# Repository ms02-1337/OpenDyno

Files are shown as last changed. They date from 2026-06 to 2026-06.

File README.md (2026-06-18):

# OpenDyno - Open Dynamometer System

> Professional open-source motor dynamometer testing platform.







📖 **Read the full development story:** [Building a Dynamometer From Scratch](https://blog.ms02.es/posts/building-a-dynamometer-from-scratch/)

---

## Overview

**OpenDyno** is a complete open-source dynamometer software and hardware system designed for precise motor/engine performance testing. It is built primarily to control eddy current brakes (it should also support inertia brakes, though this is currently untested).

---

## Architecture

The project is divided into three core parts:

| Component | Description |
|---|---|
| **DynoPower** | A power stage PCB designed to control the energy delivered to the eddy current brake. |
| **DynoLogic** | A control PCB running custom firmware. It is responsible for controlling the entire system, executing the logic software, running the PID loops, and managing all safety controls. |
| **DynoServer**| A Flask-based server that can run on a Raspberry Pi or any standard computer. It connects to DynoLogic via CAN bus and acts as the system's user interface. Using WebSockets, it serves a webpage to the browser, allowing the user to configure settings, start/stop tests, store and analyze data, and monitor the brake in real time. |

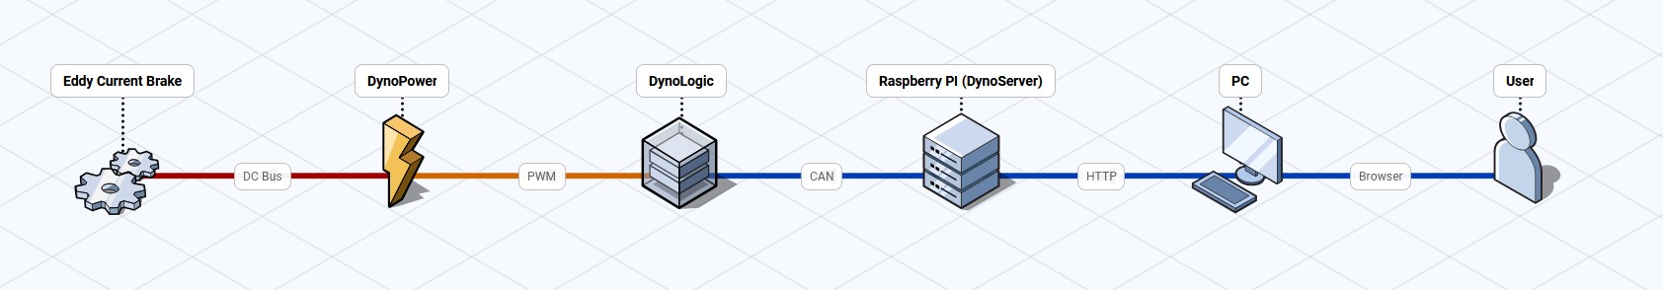
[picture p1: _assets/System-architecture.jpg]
System Architecture


### Auxiliary Hardware
- **IGBT Power**: An auxiliary power supply board that converts AC mains to 15V to power the IGBT gate driver on the DynoPower board.
  - *Note*: This board is designed to output both +15V and -5V, but **only the positive (+15V) components need to be populated** for the OpenDyno system.

## System

### DynoLogic
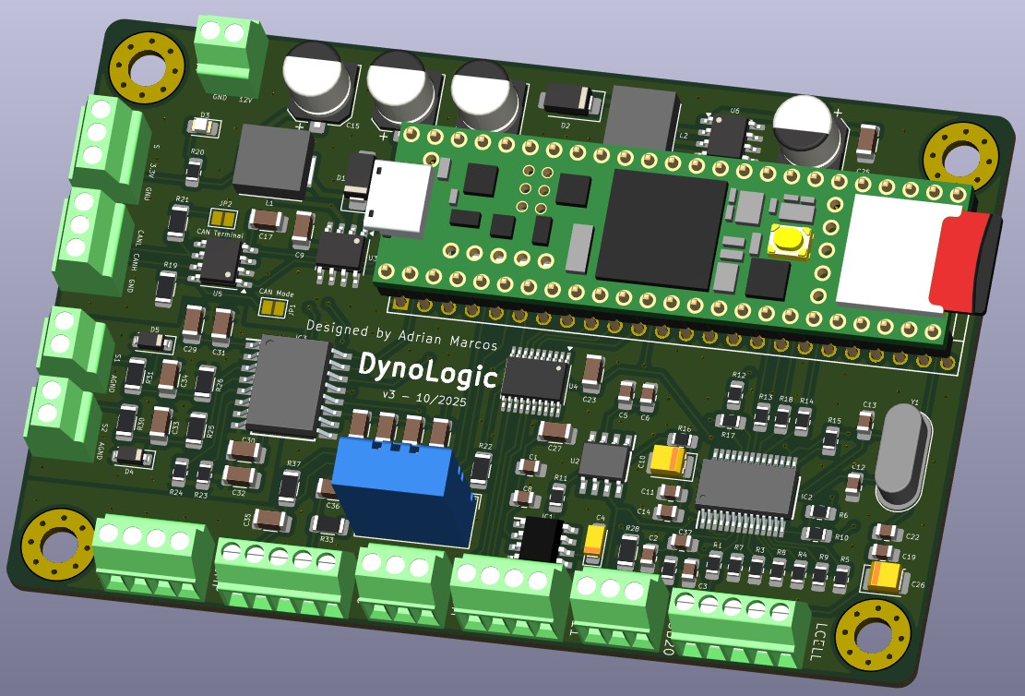
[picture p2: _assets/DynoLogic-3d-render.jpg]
DynoLogic 3D Render


### DynoPower
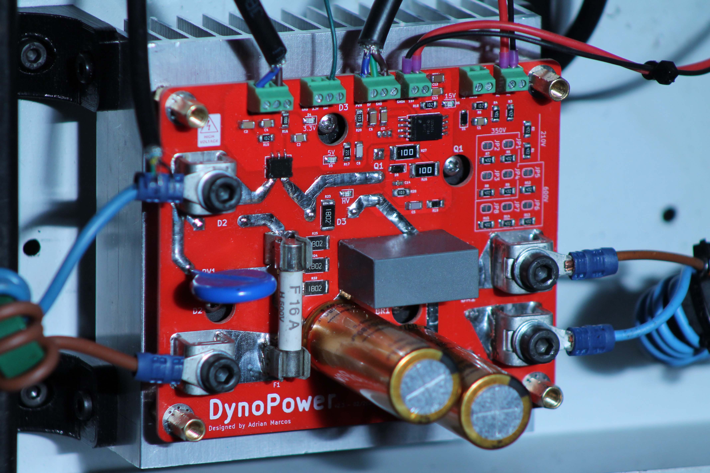
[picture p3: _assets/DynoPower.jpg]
DynoPower PCB


### DynoServer
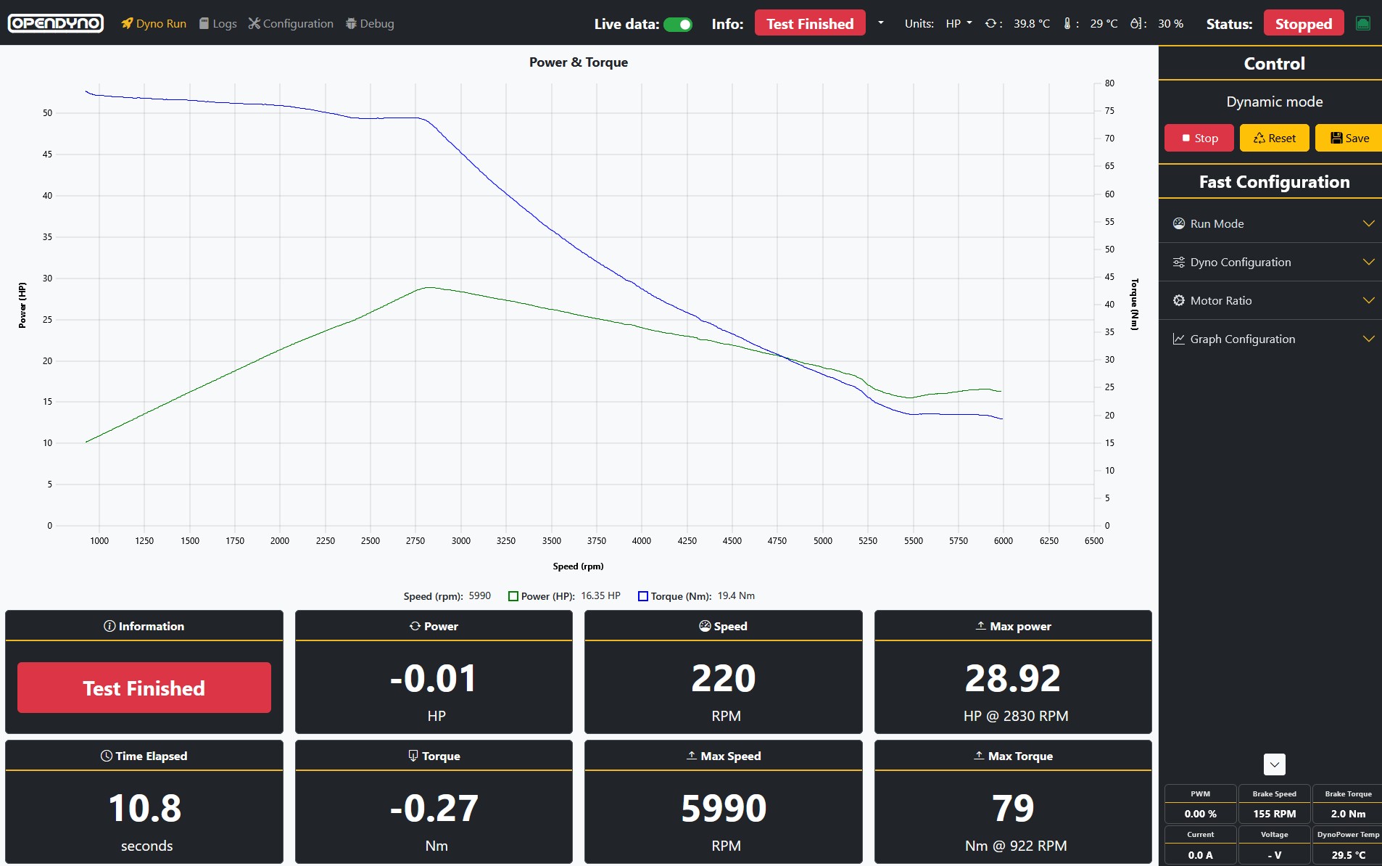
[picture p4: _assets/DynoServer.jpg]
DynoServer


---

## Key Features

- **Four Control Modes**: Constant Torque, Constant Speed, Dynamic Testing (automated state machine), and Acceleration Rate Control.
- **Real-Time Telemetry**: 100 Hz live data streaming (speed, torque, power, acceleration) via WebSocket.
- **PID Control**: High-frequency closed-loop PID control running at 1 kHz for maximum responsiveness.
- **Data Filtering**: Built-in signal processing including filters to ensure smooth and accurate sensor readings (e.g., from the load cell).
- **Thermal Monitoring**: Support for multiple temperature sensors to monitor brake and ambient temperatures.
- **Safety Limits**: User-configurable maximum speed and maximum PWM limits to protect the eddy current brake from thermal runaway, alongside minimum speed protection, a heartbeat watchdog, and emergency stop.
- **Web Interface**: Responsive UI with live charts.
- **Test Comparison**: Built-in capability to overlay and compare two different test runs directly within the user interface.
- **Selectable Power Units**: Toggle between Kilowatts (kW) and Horsepower (HP) for power measurements.

---

## Operating Modes

OpenDyno supports multiple test modes to thoroughly characterize your motor/engine:

### 1. Dynamic Mode
Automates an entire test run (e.g., accelerating from a minimum to a maximum speed and then decelerating). It uses a state machine to guarantee repeatable and standardized power sweeps.

Watch Dynamic Mode Demonstration (https://www.youtube.com/watch?v=INsLh71qHK4)

### 2. Acceleration Mode
Maintains a constant acceleration rate (RPM/s) to smoothly sweep through the motor's power band, ensuring consistent and comparable power measurements regardless of the motor's natural acceleration.

Watch Acceleration Mode Demonstration (https://www.youtube.com/watch?v=qAJ_4WTOrgE)

### 3. Torque Mode
Applies a fixed braking torque to the motor regardless of the speed. Useful for thermal testing and checking steady-state efficiency under a specific load.

Watch Torque Mode Demonstration (https://www.youtube.com/watch?v=ek7U6__xOJI)

### 4. Speed Mode
Adjusts the braking force dynamically to hold the motor at an exact RPM, regardless of the throttle position. Perfect for mapping fuel or ignition tables across different RPM bands.

Watch Speed Mode Demonstration (https://www.youtube.com/watch?v=3TeC_TSMF24)

---

## Hardware Specifications

### DynoLogic Control Board
- **MCU**: Teensy 4.1 (600 MHz ARM Cortex-M7)
- **Encoder**: Quadrature input, 50 PPR ×4 (200 counts/rev) with DWT cycle-counter timing
- **Load Cell**: 24-bit ADC (HX711 or ADS1220 selectable at compile time)
- **Brake Control**: 16-bit PWM @ 1 kHz on pin 4
- **Sensors**: MLX90614 IR temperature, BME280 (T+RH), DS18B20, Hall current sensor
- **Communication**: CAN 2.0B @ 500 kbps + USB serial debug @ 500000 baud

### DynoPower Power Board
- **Power Stage**: IGBT-based eddy current brake power stage with isolated gate drive. Rated for up to 1200V and 160A.
- **Rectification**: GBJ5010 bridge rectifier + bulk capacitance
- **Protection**: Thermal monitoring
- **Connectors**: High-current power terminals + 4-pin control interface

### Pinouts & Connectors
See detailed pin assignments in `DynoLogic/README.md` and KiCad schematics.

---

## Getting Started

Building and configuring the OpenDyno system is a multi-step process that involves:

1. Manufacturing and assembling the PCBs (DynoPower, DynoLogic, IGBT Power).
2. Sourcing the components and sensors.
3. Wiring the system.
4. Flashing the DynoLogic firmware.
5. Deploying and configuring the DynoServer software.

To make this process as smooth as possible, we have compiled a comprehensive, chronological step-by-step guide.

> [!IMPORTANT]
> **Please follow the full setup guide here:** [GETTING_STARTED.md](GETTING_STARTED.md)

For detailed configuration parameters and deep-dive technical references, consult the respective component documentation:
- **DynoLogic Reference**: [DynoLogic/README.md](DynoLogic/README.md)
- **DynoPower Reference**: [DynoPower/README.md](DynoPower/README.md)
- **DynoServer Reference**: [DynoServer/README.md](DynoServer/README.md)

---

## Documentation

| Document | Location | Description |
|---|---|---|
| DynoLogic Reference | `DynoLogic/README.md` | Hardware assembly, firmware compilation, CAN protocol, and configuration parameters |
| DynoPower Reference | `DynoPower/README.md` | Complete guide for the IGBT power stage and brake driver |
| DynoServer Reference| `DynoServer/README.md` | Complete guide for headless Raspberry Pi deployment with systemd |

---

## Safety Warning

⚠️ **This system controls high-power rotating machinery and eddy current brakes.**

- Always use an emergency stop within immediate reach
- Verify all mechanical couplings before applying power
- Never exceed the mechanical or thermal limits of your brake or motor
- Test PID gains at low power first
- Follow all local electrical and mechanical safety regulations

---

## ⚠️ Critical Power-On Sequence

**DynoPower MUST be connected to AC mains ONLY AFTER DynoLogic has fully started and the web UI shows "Connected".**

Failure to follow this sequence can result in:
- Uncontrolled brake actuation on power-up
- Damage to power electronics or eddy current brake

**Correct startup order:**
1. Power on DynoLogic (Teensy boots, firmware initializes)
2. Start DynoServer and verify CAN connection (green "Connected" indicator)
3. **Then** apply AC mains power to DynoPower

**Shutdown order (reverse):**
1. Stop any running test via web UI
2. Remove AC mains power from DynoPower first
3. Power off DynoLogic / DynoServer

---

## Notes to Users

- The system has only been tested with a few amps of power, even though the IGBT supports up to 160A.
- The MAX22530AWE has not been tested in the system. The schematic measures voltage, but isolation has not been tested, and the code for it is not written yet.

---

## License

This project is released under the **Creative Commons Attribution-NonCommercial-ShareAlike 4.0 International (CC BY-NC-SA 4.0)** license:

- ✅ Free to use for personal, educational, and research purposes
- ✅ Must provide attribution to the original authors
- ❌ **Not permitted for commercial use** or any activity that generates revenue
- 🔄 Any modifications or derivative works **must be published** under the exact same license

See the full [LICENSE](LICENSE) file for legal text.

---

*Use at your own risk.*

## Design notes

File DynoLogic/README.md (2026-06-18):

# DynoLogic

> Real-time embedded dynamometer controller (Teensy 4.1) with multi-mode PID control and CAN bus communication.

Part of the **OpenDyno** motor dynamometer system.

## 1. Firmware Configuration (`config.h`)

For a complete step-by-step assembly and setup guide, please see [../GETTING_STARTED.md](../GETTING_STARTED.md). 

The firmware provides several compile-time parameters that must be set to match your exact hardware setup. These are found in **`Firmware/include/config.h`**.

### Load Cell Type (CRITICAL)
The DynoLogic board supports two different ADCs for the load cell. You **must** define exactly one of them in `config.h` by uncommenting the appropriate line:
```cpp
// LOAD CELL SELECTION
//#define USE_HX711_LOAD_CELL                 // External HX711 amplifier (legacy)
#define USE_ADS1220_LOAD_CELL                 // Internal ADS1220 24-bit ADC (default for DynoLogic v3)
```

### Encoder Resolution
Set the number of pulses per revolution (PPR) of your rotary encoder. The firmware uses hardware quadrature decoding, so the actual counts per revolution will be 4× this value.
```cpp
#define ENC_PPR 50                            // Base resolution of your encoder
#define ENC_REVERSE_DIRECTION 1               // Reverse quadrature sign to ensure positive RPM
```

### Brake Safety Limits
Set hard limits for the PWM duty cycle and operating speeds to prevent thermal runaway or mechanical failure.
```cpp
#define DEFAULT_MAXIMUM_SPEED 4500            // Maximum operating speed [RPM]
#define DEFAULT_MAX_PWM_OUTPUT 330            // Maximum PWM value
```

### Signal Filtering
The system uses cascaded low-pass filters to clean up noisy sensor data. You can tune the aggressiveness of these filters:
```cpp
#define LOW_PASS_FILTER_SPEED_FREQ 20.0       // Speed filter cutoff [Hz]
#define LOW_PASS_FILTER_TORQUE_FREQ 15.0      // Torque filter cutoff [Hz]
```

> [!TIP]
> While these are the default firmware values, parameters like PID gains, minimum/maximum RPM, and filter cutoffs can also be tuned live via the DynoServer web interface!

## 2. Building and Flashing

### Prerequisites
1. Install [PlatformIO](https://platformio.org/install)
2. Clone this repository
3. Connect the Teensy 4.1 via USB

### Build Commands

```bash
# Build the project
pio run

# Upload to Teensy 4.1
pio run --target upload

# Clean build artifacts
pio run --target clean

# Monitor serial output (500000 baud)
pio device monitor

# Upload and monitor in one command
pio run --target upload && pio device monitor
```

## 3. Features & Specifications

- **Multiple Control Modes**
  - Torque control mode with load cell feedback
  - Speed control mode with rotary encoder feedback
  - Acceleration control mode
  - Dynamic testing mode with automated state machine

- **High-Performance Sensors**
  - Rotary encoder with DWT cycle-counter timing for precise speed measurement
  - 24-bit load cell ADC (HX711 or ADS1220 @ 2 kSPS turbo) for torque measurement
  - MLX90614 IR temperature sensor for brake monitoring
  - Hall effect current sensor
  - Environmental sensors (BME280, DS18B20)

- **Real-Time Control**
  - 1ms PID control loop (1000Hz update rate)
  - Multi-rate task scheduling (1ms, 10ms, 100ms, 500ms, 1s, 5s)
  - Configurable cascaded low-pass filtering

- **Safety Features**
  - Configurable speed limits (min/max)
  - PWM output limits
  - Configuration checksum validation
  - Heartbeat monitoring

## 4. Hardware Setup

The DynoLogic control board (`DynoLogic_v3`) is the brains of the operation. It interfaces with the sensors and controls the eddy current brake via the DynoPower board.

- **Schematics & PCB**: The full KiCad 7 project is located in `Hardware/`.
- **Manufacturing**: To manufacture the PCB, use the pre-generated Gerbers found at `Hardware/Gerbers/DynoLogic_v3.zip`.
- **Assembly**: Use the interactive bill of materials at `Hardware/bom/ibom.html` to easily place and solder components.

### Pin Assignments
```
┌─────────────────────────────────────────────────────────────────┐
│                    Teensy 4.1 Pin Assignments                   │
├─────────────────────────────────────────────────────────────────┤
│  PWM Output (Brake)                                             │
│  ├── Pin 4: PWM output (16-bit, 1kHz)                           │
│                                                                 │
│  Encoder (Quadrature)                                           │
│  ├── Pin 2: Phase A (interrupt, rising edge)                    │
│  ├── Pin 3: Phase B (interrupt, rising edge)                    │
│                                                                 │
│  Load Cell (HX711 - Alternative)                                │
│  ├── Pin 8: CLK (clock)                                         │
│  ├── Pin 9: DAT (data)                                          │
│                                                                 │
│  Load Cell (ADS1220 - Default, shares SPI0 with MAX22530)       │
│  ├── Pin 10: CS (chip select)                                   │
│  ├── Pin 41: DRDY (data ready, ISR-driven)                      │
│  └── SPI0: MOSI=11, MISO=12, SCK=13                             │
│                                                                 │
│  Temperature Sensors                                            │
│  ├── Pins 16/17: BME280 on Wire1 (SCL1/SDA1, addr 0x76)         │
│  ├── Pin 15: OneWire bus (DS18B20)                              │
│  └── Wire (I2C0): MLX90614 IR temperature sensor                │
│                                                                 │
│  Current/Voltage Measurement                                    │
│  ├── Pin A10: Hall effect current sensor (12-bit ADC)           │
│  ├── Pin 0:  MAX22530 CS (hardware feature, unused in firmware) │
└─────────────────────────────────────────────────────────────────┘
```

## 5. System Architecture

### CAN Bus Protocol
- **Microcontroller → Server**: `0x01 - 0x13`
- **Server → Microcontroller**: `0x100 - 0x126`

### Multi-Rate Control Loop
```
┌──────────────────────────────────────────────────────────────┐
│  1ms Timer ISR                                               │
│  └── Sets timing flags for multi-rate scheduling            │
├──────────────────────────────────────────────────────────────┤
│  Main Loop                                                   │
│  ├── 1ms:  PID control (1000Hz)                             │
│  ├── 10ms: Real-time data transmission                      │
│  ├── 100ms: CAN TX/RX, electrical data                      │
│  ├── 500ms: System status, LED heartbeat                    │
│  ├── 1s: Temperature readings, config reset                 │
│  └── 5s: Maintenance tasks                                  │
└──────────────────────────────────────────────────────────────┘
```

### Signal Processing Chain
```
Raw Sensor Data
    │
    ▼
Cascaded Low-Pass Filter (configurable cutoff)
    │
    ▼
Control System / CAN Transmission
```

## 6. Directory Structure

- `Firmware/` – PlatformIO C++ firmware (`src/`, `include/`, `platformio.ini`)
- `Hardware/` – KiCad 7 project (`DynoLogic_v3`), libraries, BOM, backups

## 7. Safety Considerations

> [!CAUTION]
> This system controls high-power eddy current brakes. Ensure:
> - Proper mechanical mounting and coupling
> - Emergency stop functionality is tested
> - Load cell is properly calibrated before use
> - Speed limits are configured appropriately for your equipment
> - PWM limits are set conservatively on first use
> - System is monitored during operation

## License

Licensed under the OpenDyno custom non-commercial license. See root [LICENSE](../LICENSE).

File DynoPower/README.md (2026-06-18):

# DynoPower

> Isolated power electronics board for eddy current brake control.

Part of the **OpenDyno** motor dynamometer system.

## Contents

- `DynoPower_v2/` – KiCad 7 project for the main brake driver
  - `lib/` – Custom component libraries and 3D STEP models
  - `bom/ibom.html` – Interactive bill of materials
- `IGBT_Power/` – KiCad 7 project for the IGBT Driver Power Supply

## Key Features

- IGBT-based brake driver with isolated gate drive (UCC5304)
- GBJ5010 bridge rectifier + bulk capacitance
- Snubber networks and protection circuitry
- High-current power terminals

## Important Safety & Operation Notes

> [!CAUTION]
> **HIGH VOLTAGE**: This board handles dangerous high voltages. Exercise extreme caution and do not touch the board or its terminals while it is powered on. Always allow time for the bulk capacitance to discharge after powering off before handling the board.

> [!WARNING]
> **POWER-ON SEQUENCE**: You must ALWAYS follow the correct power sequencing to avoid unexpected brake engagement or hardware damage:
> 1. Power on the **DynoLogic** controller first.
> 2. Ensure the DynoServer web interface shows a successful **Connected** status.
> 3. **ONLY THEN** should you connect the DynoPower board to AC mains.
> 4. When shutting down, disconnect DynoPower from AC mains *before* powering off DynoLogic.

> [!IMPORTANT]
> **THERMAL MANAGEMENT**: The IGBT on this board is rated for up to 160A. However, a typical eddy current brake will draw between 15A to 45A. If you are operating the brake under constant load for extended periods, the board **will require active cooling (fans)** and a substantial heatsink to dissipate the generated heat.

## Documentation

See the main [OpenDyno README](../README.md#hardware-specifications) for specifications and the KiCad project for schematics and fabrication files.

## License

Licensed under the OpenDyno custom non-commercial license. See root [LICENSE](../LICENSE).

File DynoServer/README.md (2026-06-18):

# DynoServer

> Flask + Socket.IO web application providing real-time visualization, CAN communication, and test logging for the OpenDyno dynamometer.

Part of the **OpenDyno** motor dynamometer system.

## 1. Server Configuration (`.env`)

For a complete step-by-step assembly and setup guide, please see [../GETTING_STARTED.md](../GETTING_STARTED.md).

Before starting the server, you must copy the `.env.example` file to `.env` and configure your environment variables. The `.env` file controls all networking, security, and hardware interface settings.

### Network Settings
- **`HOST` / `PORT`**: Defines where the Flask server binds. Use `0.0.0.0` and `9000` to make it accessible across your local network.
- **`ALLOWED_ORIGINS`**: Essential for CORS. To allow access from any device on your local network, set this to `*`. In a strict production environment, specify the exact IP addresses allowed to access the server.

### Hardware Interface
- **`CAN_TTY_DEVICE`**: Defines the USB path to your slcan-compatible CAN adapter (e.g., `/dev/ttyACM0` or `/dev/ttyUSB0`). Ensure this matches your physical hardware path.
- **`CAN_INTERFACE`**: Typically `socketcan`.
- **`CAN_CHANNEL`**: Typically `slcan0`.

### Security
- **`SECRET_KEY`**: Ensure you change this to a long, secure, randomly generated string for production deployments.

## 2. Automated Service Deployment (Linux/Raspberry Pi)

DynoServer includes several bash scripts in the root directory to completely automate deployment on a Linux machine (like a Raspberry Pi). 

1. **`setup_can_sudo.sh`**: Grants passwordless execution privileges for `slcan_attach` and `ifconfig` to all users. This allows the Flask backend to dynamically toggle and initialize the CAN bus interface directly from the web UI without prompting for a password.
2. **`init_can.sh`**: Physically brings up the `slcan0` network interface using your configured `CAN_TTY_DEVICE` at 500 kbps.
3. **`install_service.sh`**: The main deployment script. Must be run as root. It creates a dedicated `opendyno` system user, automatically builds the Python virtual environment (`venv`), installs all production dependencies (`requirements/prod.txt`), executes `setup_can_sudo.sh`, and finally installs and starts the `opendyno.service` systemd daemon. *(Note: If you pull new code from GitHub later, you can simply run this script again to automatically update the dependencies and restart the service!)*

To completely deploy the server on a fresh Linux machine, simply run:
```bash
sudo ./install_service.sh
```

## 3. Manual Deployment (No Service) & Development

If you want to run the server manually without setting it up as a background systemd service (e.g., on Windows, Mac, or for local development):

1. **Create a Virtual Environment**:
   ```bash
   python3 -m venv .venv
   source .venv/bin/activate
   # Or on Windows: .venv\Scripts\activate
   ```
2. **Install Requirements**:
   ```bash
   pip install -r requirements/dev.txt
   ```
3. **Run the Application**:
   ```bash
   python run.py
   ```
   *(Note: The server will start, but CAN connectivity requires a Linux environment with `socketcan` or a compatible mock interface).*

## 4. Web Interface Configuration

Once the server is running, you can access the responsive web interface to monitor live telemetry, control the dyno, and configure the entire system dynamically. All configuration changes are sent over CAN and instantly validated via checksums.

### Configurable Parameters

| Category | Parameters | Description |
|---|---|---|
| **Dynamic Test Profile** | `startSpeed`, `rampRate`, `endSpeed`, `holdDelay`, etc. | Configures the automated state machine. Defines the RPM ramp rates, stabilization times, and peak test speeds for automated sweeping. |
| **PID Controllers** | `Kp`, `Ki`, `Kd` | Independent tuning gains for Torque, Speed, and Dynamic (Acceleration) modes. Tunable live to quickly find the perfect loop response. |
| **Load Cell Calibration** | `gain`, `offset` (Tare), `scale`, `distance` | Used to tare the load cell and set the mechanical moment arm distance (meters) to convert raw force into torque. |
| **Hardware Limits** | `minSpeed`, `maxSpeed`, `PWM limit` | Critical safety limits that prevent the eddy current brake from engaging below minimum speeds or exceeding thermal/RPM limits. |
| **Signal Filtering** | `speed_hz`, `torque_hz`, `accel_hz` | Cutoff frequencies for the cascaded low-pass filters running on the Teensy. Allows you to smooth out noisy load cell or encoder data on the fly. |
| **Inertia & Ratios** | `dynoInertia`, `motorPinions`, `dynoPinions` | Physical constants used to calculate acceleration torque and correct for chain/belt gear ratios between the motor and the brake. |
| **Graph Scaling** | `torque_max`, `rpm_max`, `power_max` | Adjusts the Y-axis constraints of the live charts so your specific motor data fits perfectly on the screen. |

## 5. Features & Architecture

- **Flask Backend**: Serves the frontend static files and handles REST API requests for configuring PID parameters and limits.
- **Socket.IO Telemetry**: Provides real-time, low-latency WebSocket streaming. Telemetry data (speed, torque, acceleration, temperatures) is pushed from the DynoLogic firmware to the browser at 100 Hz for perfectly smooth live charting.
- **Config Synchronization**: Any configuration changes made in the web UI (like Load Cell Tare, Max RPM, or PID gains) are instantly validated via CRC16 checksums and transmitted over the CAN bus to update the non-volatile memory of the Teensy 4.1.
- **Test Logging**: Dynamometer runs are automatically saved to the local `data/database.json` file for historical analysis and test comparison overlays.

## License

Licensed under the OpenDyno custom non-commercial license. See root [LICENSE](../LICENSE).

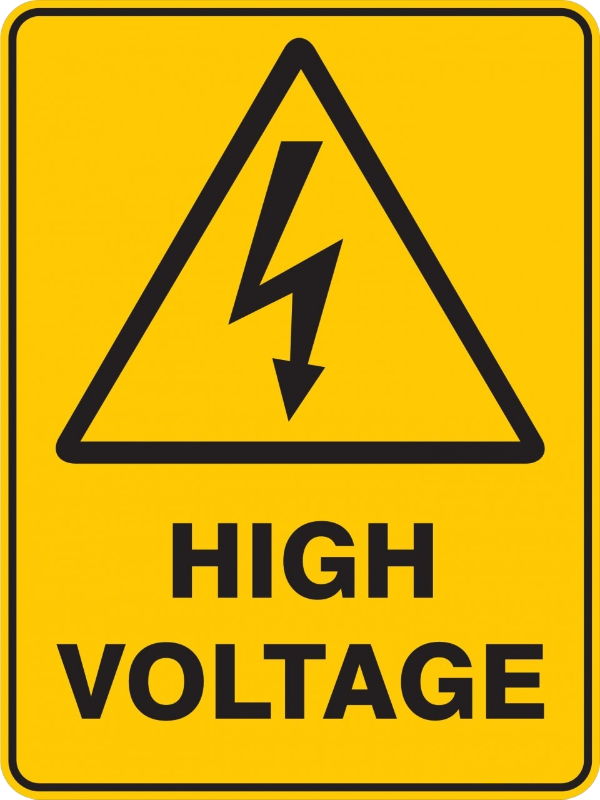
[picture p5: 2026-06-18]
DynoPower/DynoPower_v2/img/high_voltage.png

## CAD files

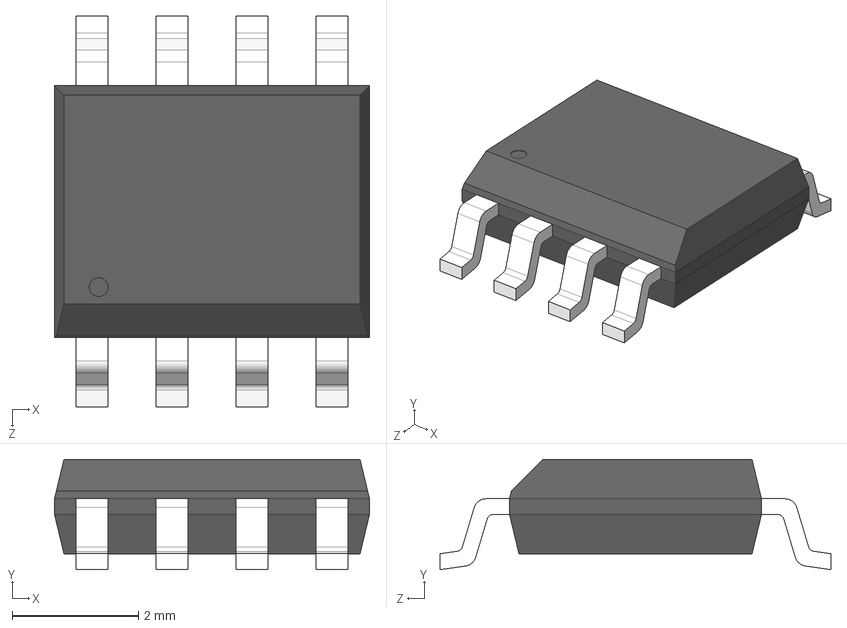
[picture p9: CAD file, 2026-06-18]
DynoLogic/Hardware/_lib/ADR03A/ADR03ARZ.stp
5.00 x 1.75 x 6.20 mm

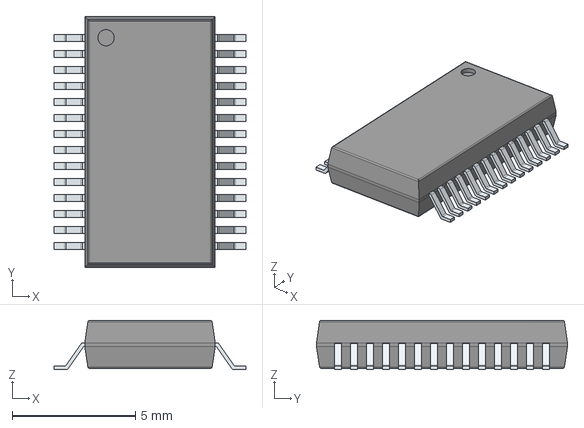
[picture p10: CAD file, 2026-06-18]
DynoLogic/Hardware/_lib/ADS1256IDBR/ADS1256IDBR.stp
7.80 x 10.2 x 2.00 mm
PinsArrayLR

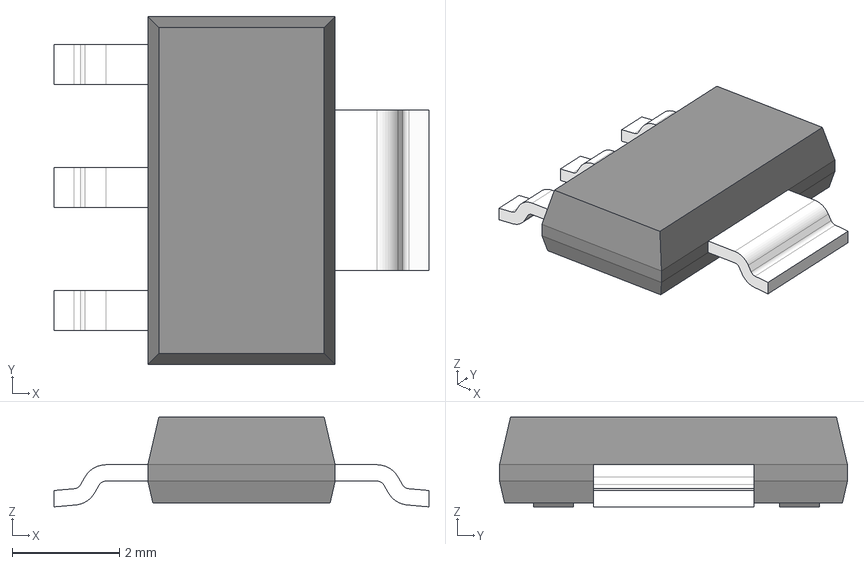
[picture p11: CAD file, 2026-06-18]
DynoLogic/Hardware/_lib/AMS1117-3.3/AMS1117-3.3.stp
7.00 x 6.50 x 1.68 mm
BODY-SOT
LEAD-SOT x 3
LEAD-SOT-WIDE
PIN1-ID

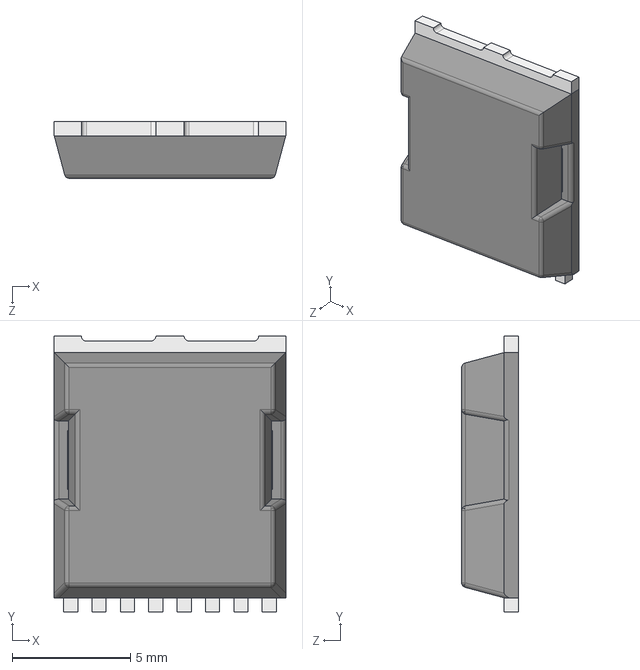
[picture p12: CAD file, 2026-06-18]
DynoLogic/Hardware/_lib/AOTL66912/AOTL66912.stp
9.80 x 11.7 x 2.40 mm
Pieza3
Pieza4

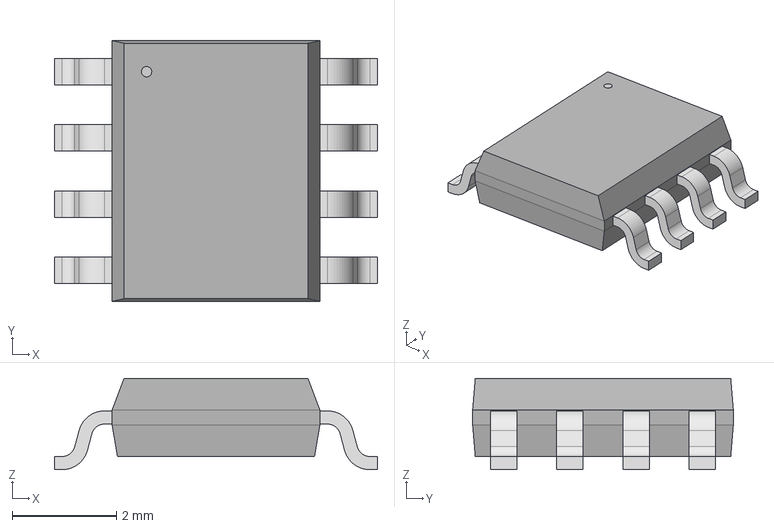
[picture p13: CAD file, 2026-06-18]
DynoLogic/Hardware/_lib/FDS6675/SOIC8_4X5_ONS.step
6.20 x 5.00 x 1.75 mm

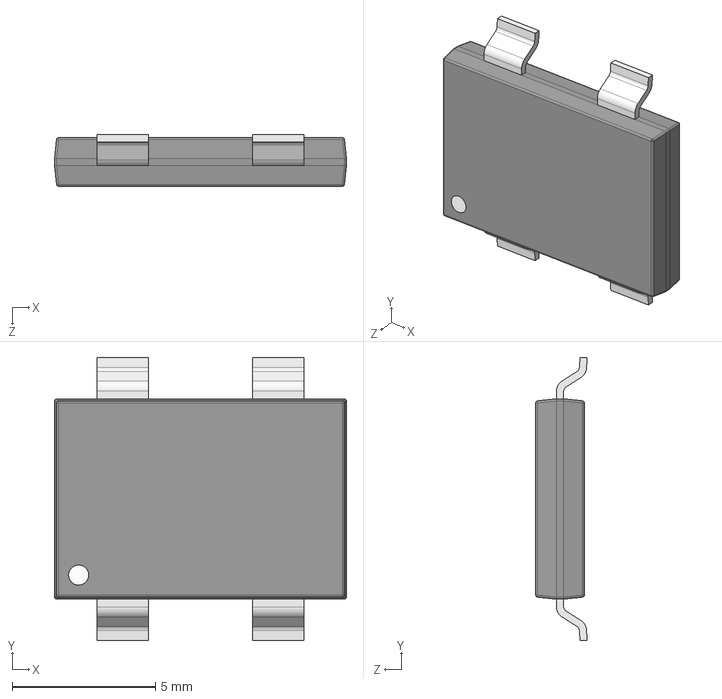
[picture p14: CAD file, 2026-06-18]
DynoLogic/Hardware/_lib/HBS510/HBS510-HF.stp
10.2 x 9.90 x 1.80 mm

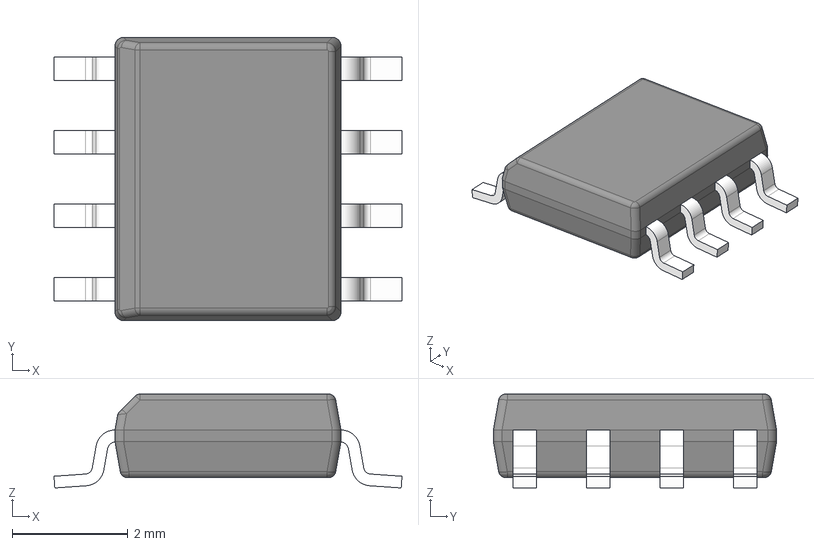
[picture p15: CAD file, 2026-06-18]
DynoLogic/Hardware/_lib/OPA350UA/OPA350UA.stp
6.02 x 4.90 x 1.63 mm
BODY-SO
LEAD-D0008A x 8

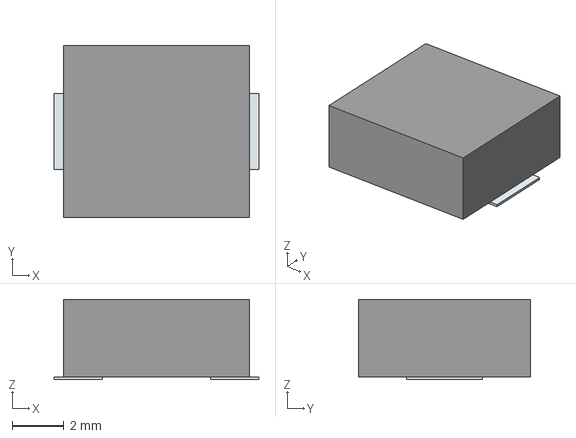
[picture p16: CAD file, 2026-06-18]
DynoLogic/Hardware/_lib/Regulator_L/Regulator_L.stp
7.93 x 6.65 x 3.10 mm
Pins

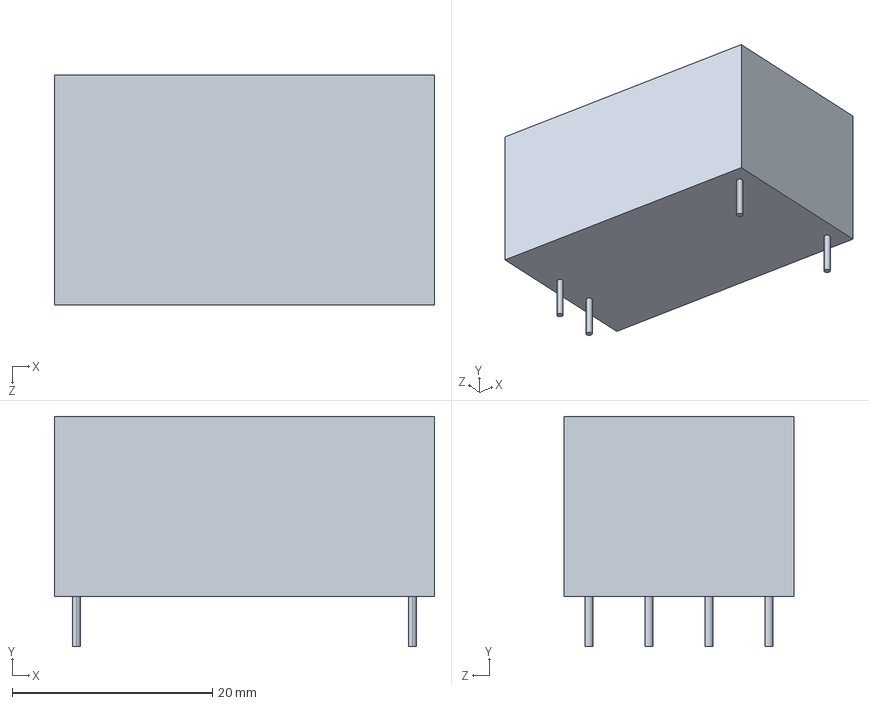
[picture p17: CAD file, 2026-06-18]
DynoPower/IGBT_Power/HLK-5M05.STEP
38.0 x 23.0 x 23.0 mm

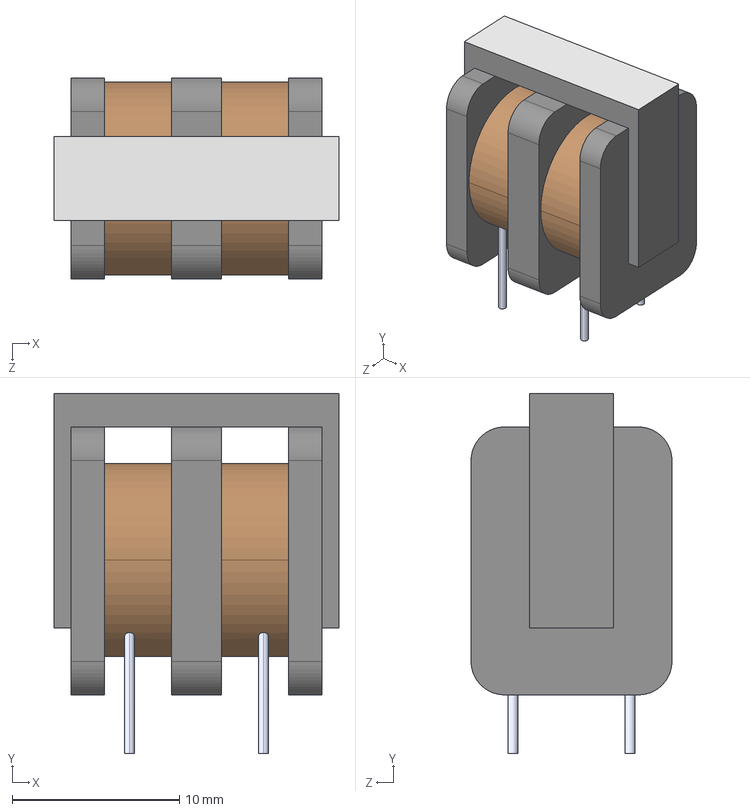
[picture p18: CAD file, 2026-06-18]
DynoPower/IGBT_Power/Inductor.STEP
17.0 x 21.5 x 12.0 mm

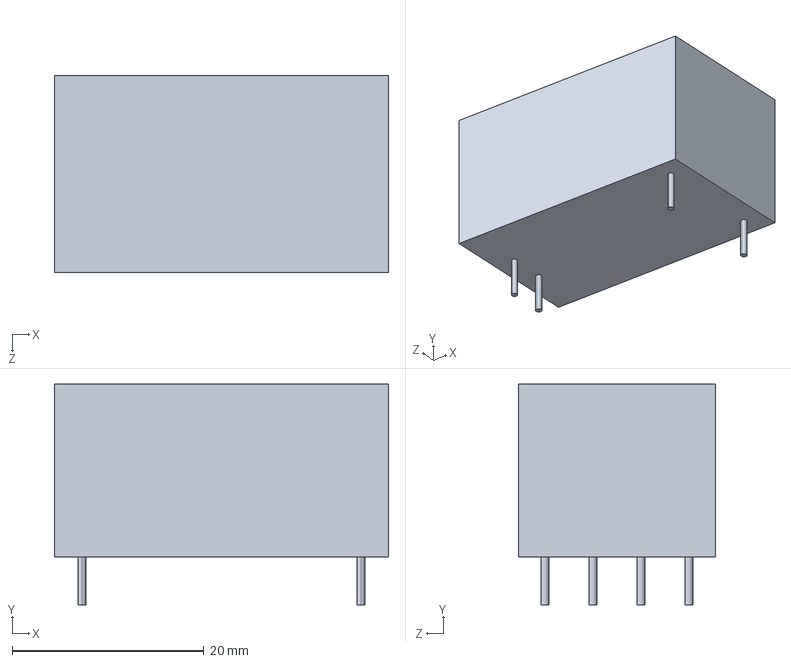
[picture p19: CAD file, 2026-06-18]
DynoPower/IGBT_Power/HLK-3M15B.STEP
34.8 x 23.0 x 20.5 mm

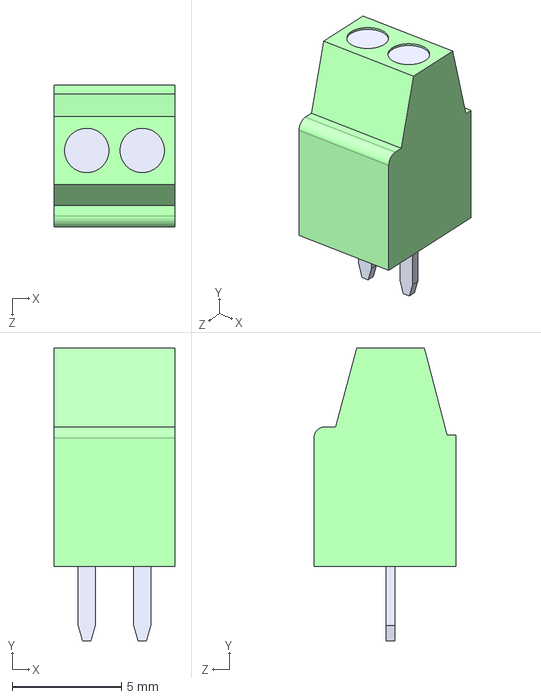
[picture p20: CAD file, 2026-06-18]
DynoLogic/Hardware/_lib/2pinConnector/39773-0002.stp
5.54 x 13.4 x 6.50 mm

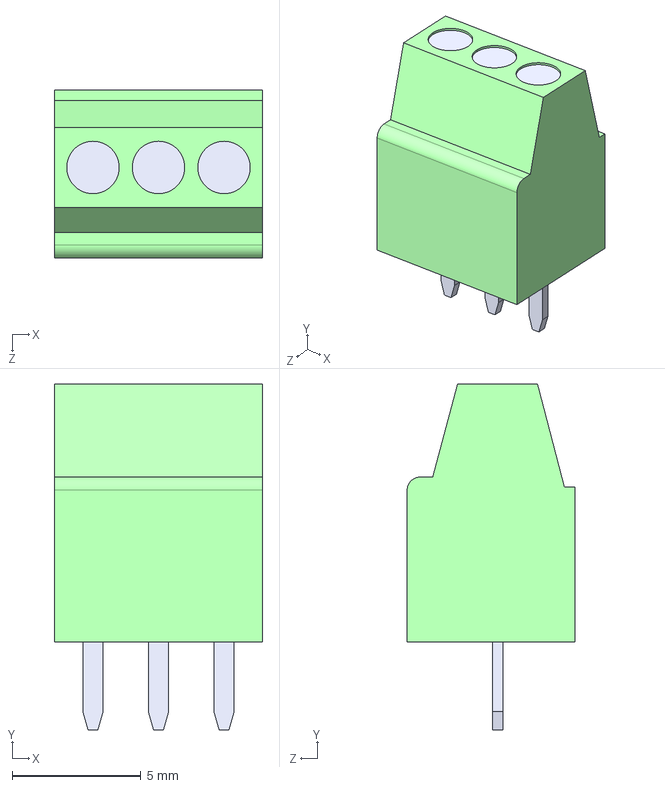
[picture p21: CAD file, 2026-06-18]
DynoLogic/Hardware/_lib/3pinConnector/39773-0003.stp
8.08 x 13.4 x 6.50 mm

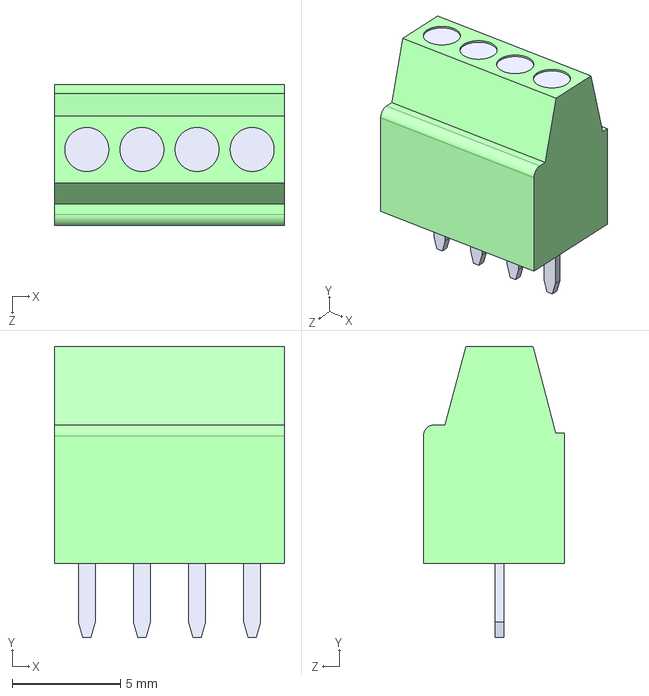
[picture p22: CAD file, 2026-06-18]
DynoLogic/Hardware/_lib/4pinConnector/39773-0004.stp
10.6 x 13.4 x 6.50 mm

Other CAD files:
DynoLogic/Hardware/_lib/5pinConnector/1725685.stp
DynoLogic/Hardware/_lib/B82442T1683K050/B82442T1683K050.stp
DynoLogic/Hardware/_lib/DMKDS/1740000.stp
DynoLogic/Hardware/_lib/MAX22530AWE/MAX22530AWE+T.stp
DynoPower/IGBT_Power/2pinConnector/39773-0002.stp
DynoPower/IGBT_Power/3pinConnector/39773-0003.stp

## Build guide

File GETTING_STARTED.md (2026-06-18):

# Getting Started with OpenDyno

This guide walks you through the step-by-step process of manufacturing, assembling, wiring, and configuring the OpenDyno system.

---

## 1. Hardware Acquisition & Manufacturing

### PCB Manufacturing
The system requires three custom PCBs to be manufactured. You can use services like JLCPCB. Small PCB designs have been made to be cheap to produce. For convenience, pre-generated Gerber ZIP files are available to send directly to the manufacturer:
1. **DynoPower Board**: A ready-to-send ZIP is available at [DynoPower_v2.zip](DynoPower/DynoPower_v2/Gerbers/DynoPower_v2.zip).
2. **DynoLogic Board**: A ready-to-send ZIP is available at [DynoLogic_v3.zip](DynoLogic/Hardware/Gerbers/DynoLogic_v3.zip).
3. **IGBT Power Board**: A ready-to-send ZIP is available at [IGBT_Power.zip](DynoPower/IGBT_Power/Gerbers/IGBT_Power.zip).

### Component Sourcing
Components for the PCBs must be purchased from suppliers like LCSC, Mouser, or others, and then soldered onto the boards. 

**Buy List:**
- **Standard Components**: Refer to the interactive BOMs (`ibom.html`) for the exact resistors, ICs, etc., sourced from LCSC or Mouser.
- **Teensy 4.1**: Required for the DynoLogic board (can be purchased from PJRC or Aliexpress).
- **Connectors**: [Signal and power connectors](https://es.aliexpress.com/item/1005001677869988.html) for DynoLogic and DynoPower (excluding high-current terminals).
- **Capacitors**: [High-voltage capacitors](https://es.aliexpress.com/item/1005008575894112.html) for the DynoPower board.
- **Heatsink & Thermals**: [Large heatsink](https://es.aliexpress.com/item/33021705659.html) and [thermal pads](https://es.aliexpress.com/item/32880831473.html) for the IGBT on the DynoPower board.
- **CAN Adapter**: [CANable adapter](https://es.aliexpress.com/item/1005006842262016.html) to connect DynoLogic to DynoServer.

**External Hardware (To be purchased separately):**
- **IR Temp Sensor**: [IR Temperature sensor](https://es.aliexpress.com/item/1005005964068723.html)
- **Encoder**: [Rotary encoder](https://es.aliexpress.com/item/1005005071771659.html)
- **Load Cell**: [Load cell](https://es.aliexpress.com/item/1005005915852645.html)
- **Load Cell Amp**: [HX711 module](https://es.aliexpress.com/item/1005006293368575.html)

### Compute & Communication
- **Server Hardware**: A Raspberry Pi, OrangePi, or any standard computer is needed to run the DynoServer software.
- **CAN Adapter**: The CANable (or compatible) adapter mentioned above is required to connect the DynoLogic board to the DynoServer.

### Eddy Current Brake
> [!WARNING]
> You must carefully check the specifications of your eddy current brake. It is highly recommended to wire it for **192V** operation. Ensure your wiring and the brake's insulation can safely handle this voltage.

---

## 2. Assembly & Connections

Once all boards are populated and external sensors are acquired, wire the system together following the diagram below:

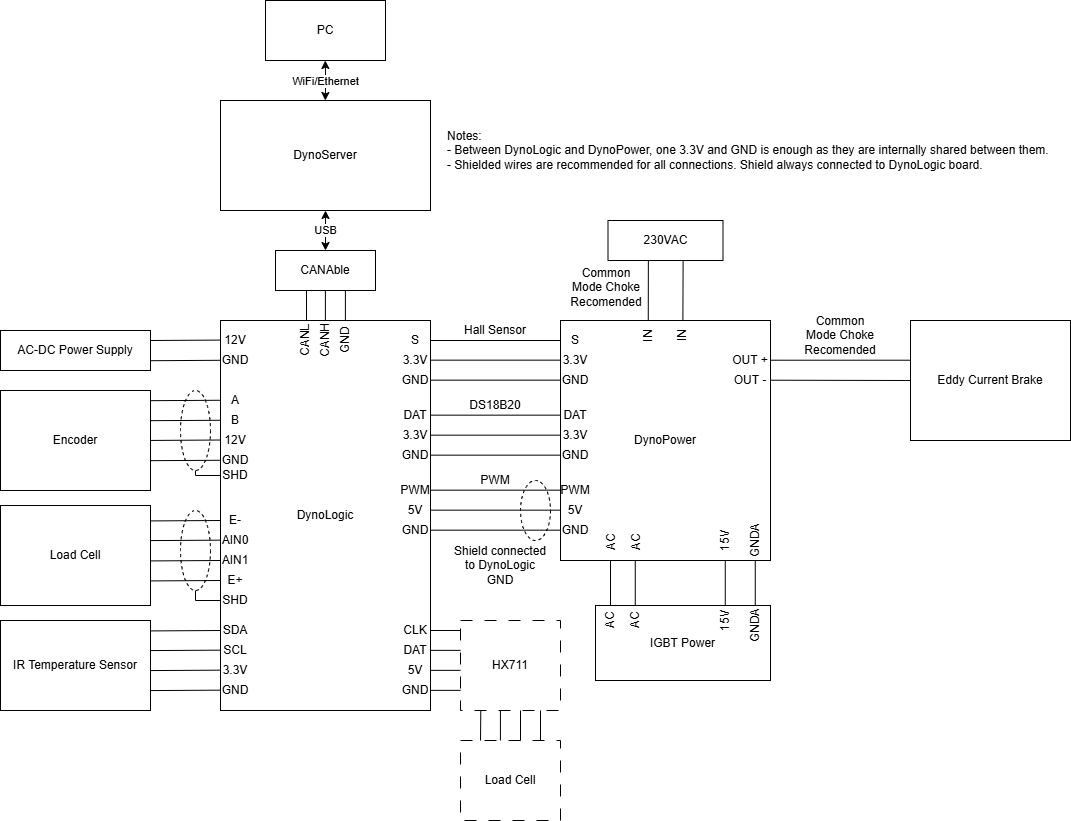
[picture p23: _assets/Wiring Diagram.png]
Wiring Diagram


---

## 3. Firmware Setup (DynoLogic)

Once the hardware is connected, you need to configure and flash the control firmware.

1. **Configure Firmware**: Open the `DynoLogic/Firmware` project in PlatformIO. Adjust any necessary compile-time parameters for your specific hardware setup. For a deep dive into available configuration parameters, consult `DynoLogic/README.md`.
2. **Flash to Teensy**: Burn the compiled firmware into the Teensy 4.1 via USB.

---

## 4. Server Setup (DynoServer)

With the firmware running, set up the web interface and control server.

1. **Configuration Files**: Navigate to `DynoServer/`. Copy the `.env.example` file to `.env` and configure your environment variables. For a deep dive into available configuration parameters and deployment scripts, consult `DynoServer/README.md`.
2. **Deploy Service**: Install the necessary dependencies and deploy the service (e.g., using the provided `install_service.sh` for Linux). 
3. **Start Service**: Start the DynoServer application and ensure it successfully connects to the CANable adapter.

---

## 5. Calibration & Interface Setup

After launching the DynoServer and accessing the web interface:

1. **Interface Configuration**: Set your maximum and minimum speeds, load cell parameters, and other safety limits in the web interface.
2. **Tare Load Cell**: Ensure the load cell is unloaded and tare it through the UI to zero the torque reading.
3. **PID Tuning**: Finally, carefully tune the PID parameters for your specific eddy current brake and motor dynamics. It is recommended to start tuning with low power limits to ensure safety.

Once these steps are completed, your OpenDyno system is fully operational and ready for testing!

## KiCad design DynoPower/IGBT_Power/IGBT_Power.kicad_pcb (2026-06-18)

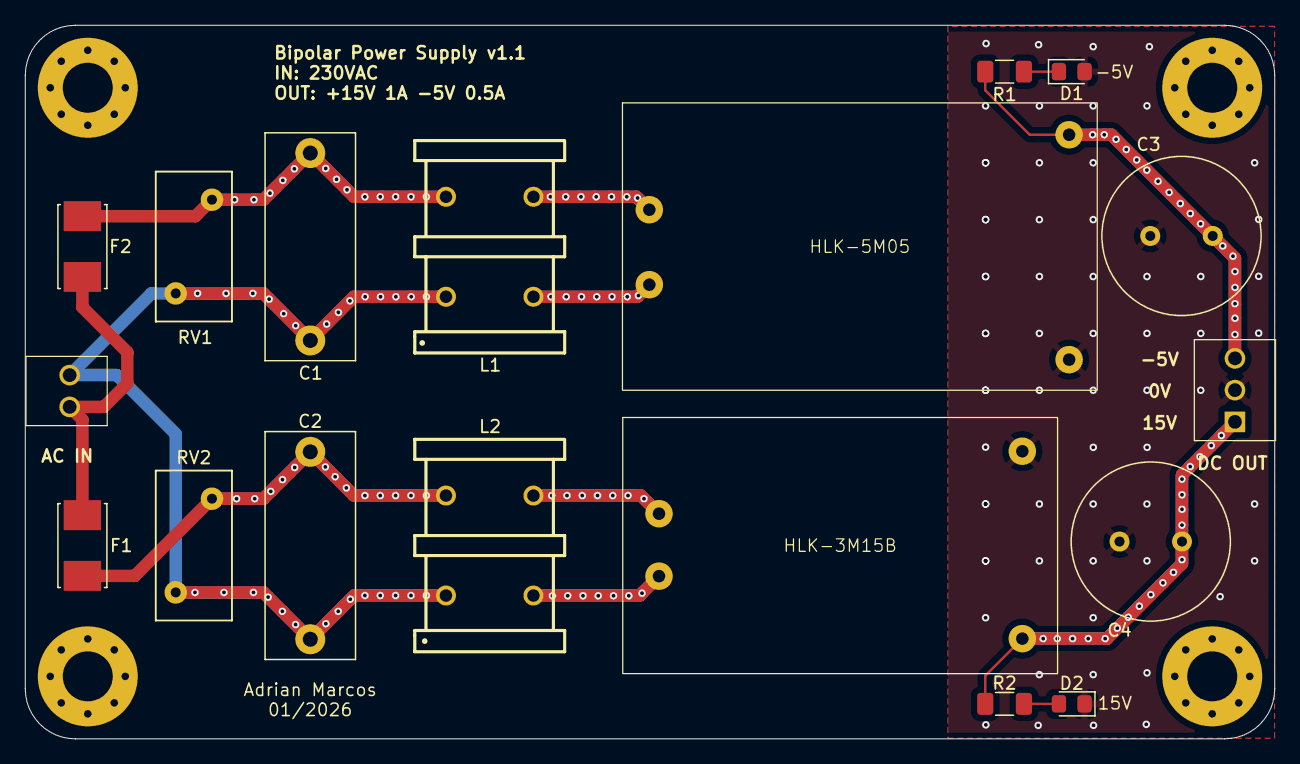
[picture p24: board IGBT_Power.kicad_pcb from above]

Board: 2 copper layers, 100.0 x 57.1 mm, 22 parts (0 on the bottom side), 13 nets.

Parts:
C1, C2: 0.1uF; C_Rect_L18.0mm_W7.0mm_P15.00mm_FKS3_FKP3
C3, C4: 220uF; C_Radial_D12.5mm_H20.0mm_P5.00mm
D1: 5V; D_0805_2012Metric_Pad1.15x1.40mm_HandSolder
D2: 15V; D_0805_2012Metric_Pad1.15x1.40mm_HandSolder
F1: 1A; Fuseholder_Littelfuse_Nano2_157x
F2: 500mA; Fuseholder_Littelfuse_Nano2_157x
HLK-3M15B: HLK-3M15B
HLK-5M05: HLK-5M05
J1: IN; 2pin
J2: OUT; 3pin
L1, L2: 15mH; 15mH_Inductor
M2, M2#2, M2#3, M2#4: MountingHole_4mm_Pad_Via
R1: 220; R_1206_3216Metric_Pad1.30x1.75mm_HandSolder
R2: 1k; R_1206_3216Metric_Pad1.30x1.75mm_HandSolder
RV1, RV2: 10D561K; RV_Disc_D12mm_W6.1mm_P7.5mm

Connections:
+15V: C4.1, HLK-3M15B.4 (V+), J2.1, R2.1
-5V: C3.2, HLK-5M05.3 (V-), J2.3, R1.2
GND: C3.1, C4.2, D1.2 (A), D2.1 (K), HLK-3M15B.3 (V-), HLK-5M05.4 (V+), J2.2
unnamed: C1.1, F2.1, L1.1, RV1.1
unnamed: C2.1, F1.1, L2.1, RV2.1
unnamed: D1.1 (K), R1.1
unnamed: D2.2 (A), R2.2
unnamed: F1.2, F2.2, J1.1
unnamed: C1.2, C2.2, J1.2, L1.4, L2.4, RV1.2, RV2.2
unnamed: HLK-5M05.1 (AC), L1.2
unnamed: HLK-5M05.2 (AC), L1.3
unnamed: HLK-3M15B.1 (AC), L2.2
unnamed: HLK-3M15B.2 (AC), L2.3

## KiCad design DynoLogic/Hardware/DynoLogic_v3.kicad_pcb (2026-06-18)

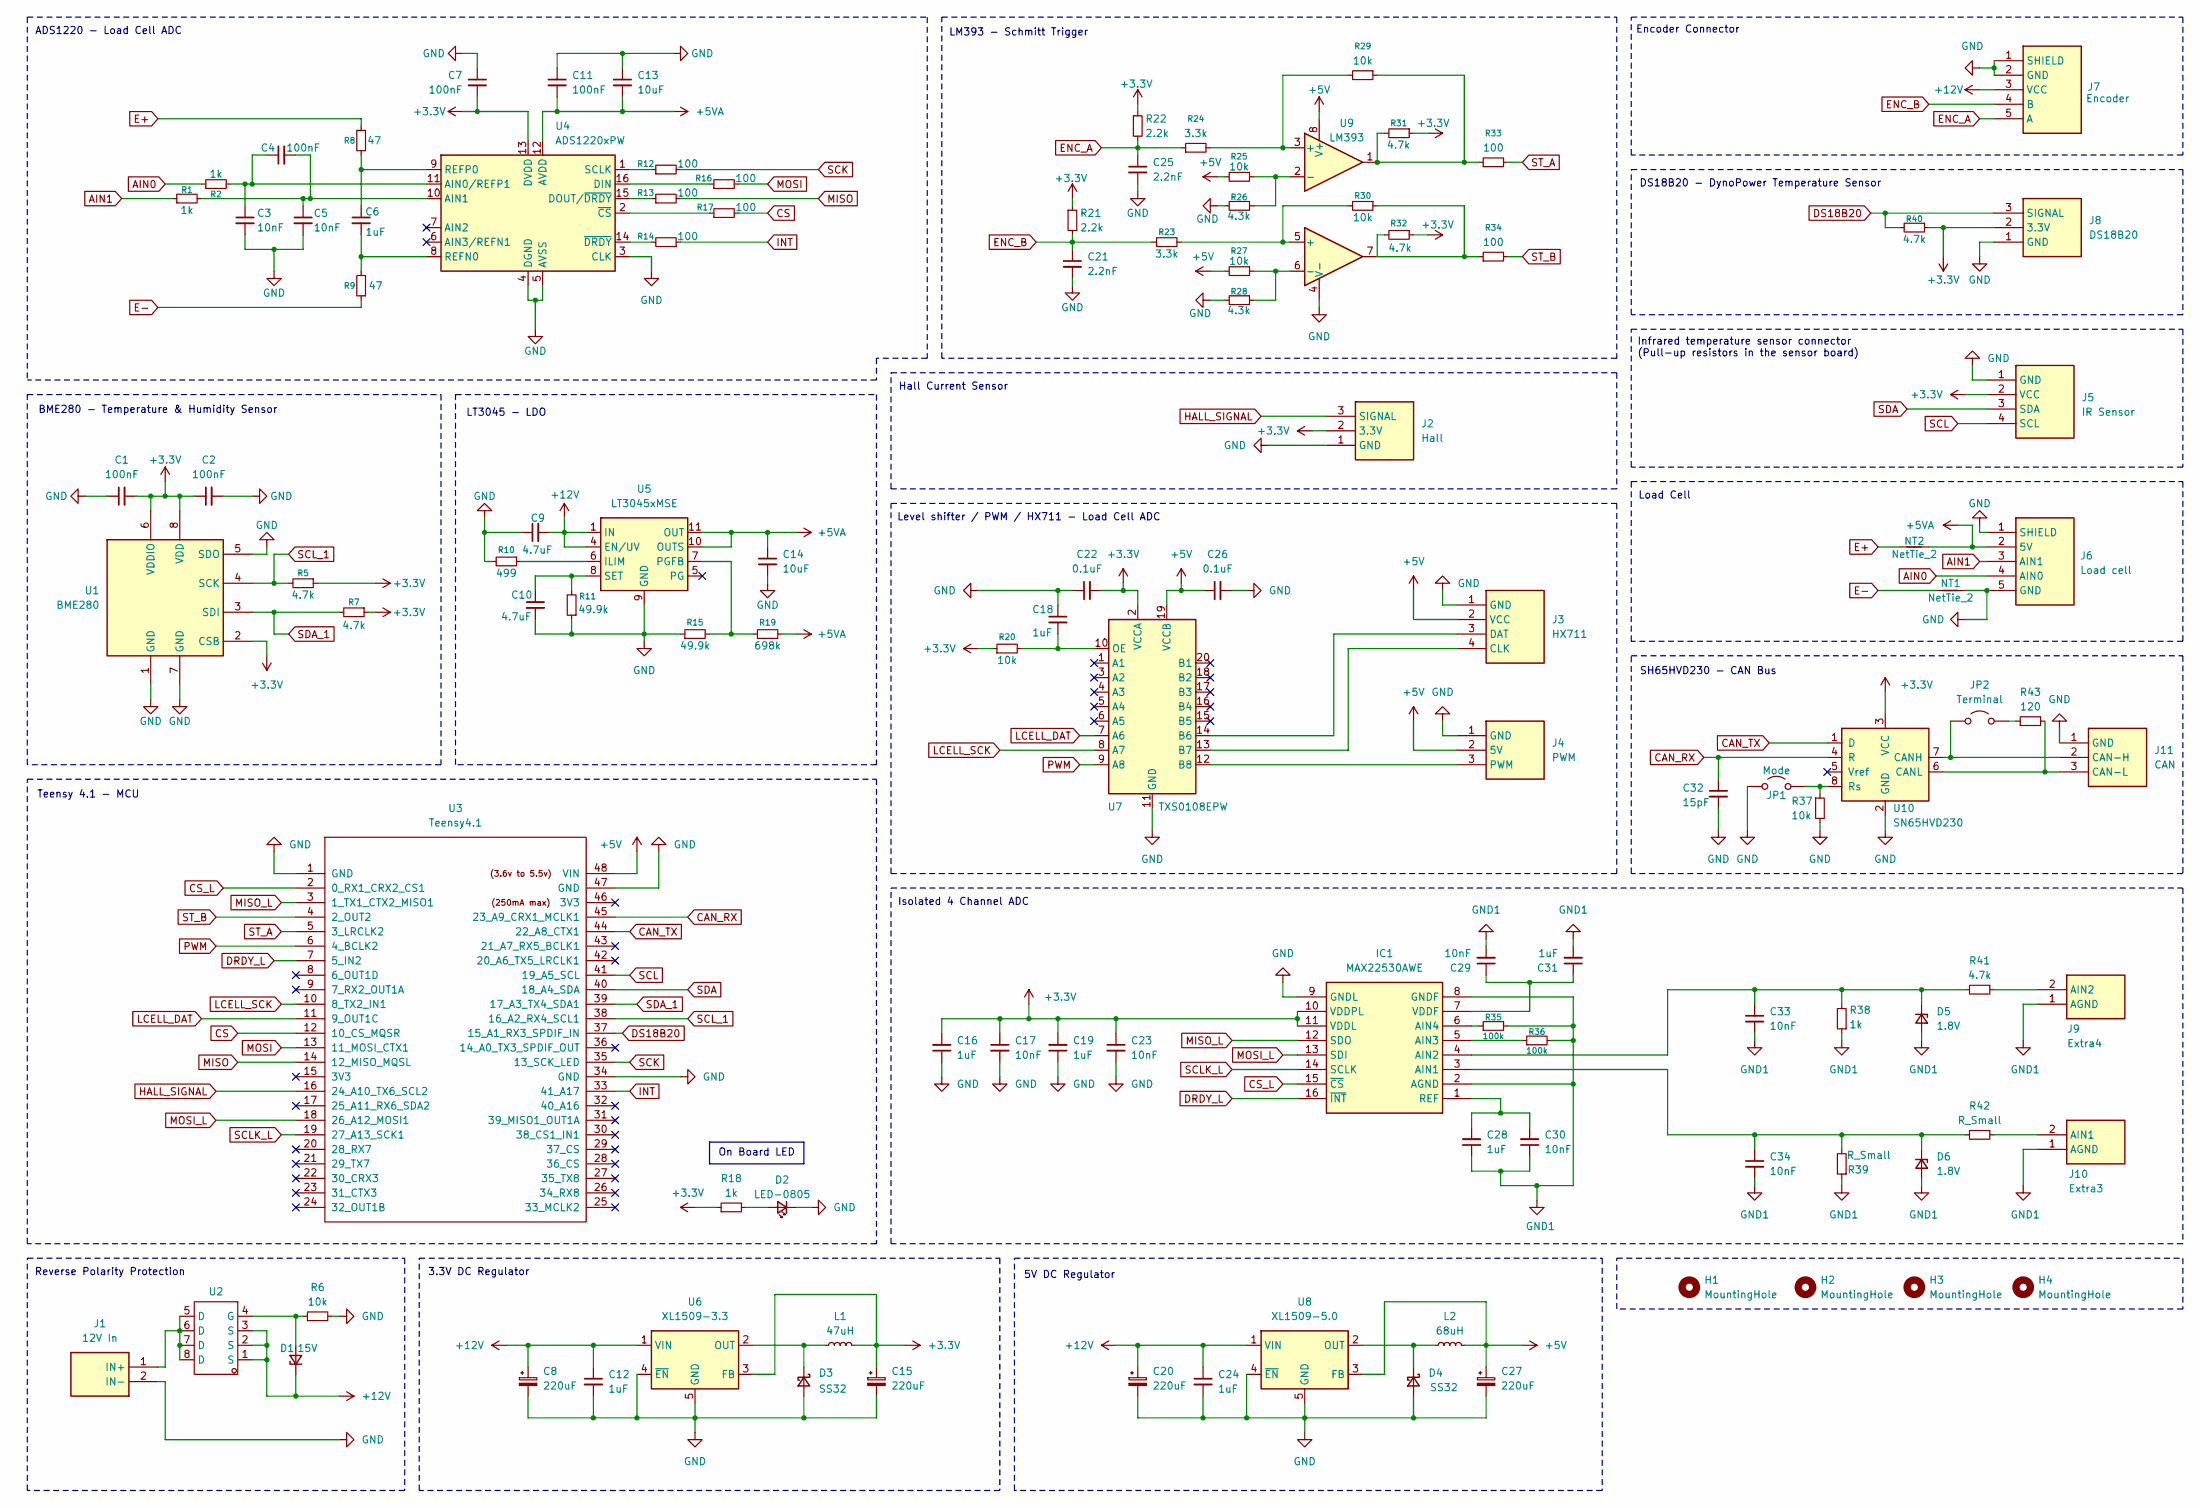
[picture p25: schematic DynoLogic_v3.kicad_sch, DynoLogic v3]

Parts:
C1, C2, C4, C7, C11: 100nF; C_1206_3216Metric
C3, C5, C17, C23, C29, C30, C33, C34: 10nF; C_1206_3216Metric
C6, C12, C16, C18, C19, C24, C28, C31: 1uF; C_1206_3216Metric
C8, C15, C20, C27: 220uF; CP_Elec_6.3x7.7
C9, C10: 4.7uF; C_1206_3216Metric
C13, C14: 10uF; C_1206_3216Metric
C21, C25: 2.2nF; C_1206_3216Metric
C22, C26: 0.1uF; C_1206_3216Metric
C32: 15pF; C_1206_3216Metric
D1: 15V; SOT-23_Handsoldering
D2: LED-0805; LED_0805_2012Metric_Pad1.15x1.40mm_HandSolder
D3, D4: SS32; D_SMA
D5, D6: 1.8V; D_SOD-123
H1, H2, H3, H4: MountingHole; MountingHole_4mm_Pad_Via
IC1: MAX22530AWE; Mouser Part Number 700-MAX22530AWET
J1: 12V In; Connector_2pin; Mouser Part Number 538-39773-0002
J2: Hall; Connector_3pin; Mouser Part Number 538-39773-0003
J3: HX711; Connector_4pin; Mouser Part Number 538-39773-0004
J4: PWM; Connector_3pin; Mouser Part Number 538-39773-0003
J5: IR Sensor; Connector_4pin; Mouser Part Number 538-39773-0004
J6: Load cell; Connector_5pin; Mouser Part Number 651-1725685
J7: Encoder; Connector_5pin; Mouser Part Number 651-1725685
J8: DS18B20; Connector_3pin; Mouser Part Number 538-39773-0003
J9: Extra4; Connector_2pin; Mouser Part Number 538-39773-0002
J10: Extra3; Connector_2pin; Mouser Part Number 538-39773-0002
J11: CAN; Connector_3pin; Mouser Part Number 538-39773-0003
JP1: Mode; SolderJumper-2_P1.3mm_Open_Pad1.0x1.5mm
JP2: Terminal; SolderJumper-2_P1.3mm_Open_Pad1.0x1.5mm
L1: 47uH; Regulator_L
L2: 68uH; Regulator_L
NT1, NT2: NetTie_2; NetTie-2_SMD_Pad0.5mm
R1, R2, R18, R38: 1k; R_1206_3216Metric
R5, R7, R31, R32, R40, R41: 4.7k; R_1206_3216Metric
R6, R20, R25, R27, R29, R30, R37: 10k; R_1206_3216Metric
R8, R9: 47; R_1206_3216Metric
R10: 499; R_1206_3216Metric
R11, R15: 49.9k; R_1206_3216Metric
R12, R13, R14, R16, R17, R33, R34: 100; R_1206_3216Metric
R19: 698k; R_1206_3216Metric
R21, R22: 2.2k; R_1206_3216Metric
R23, R24: 3.3k; R_1206_3216Metric
R26, R28: 4.3k; R_1206_3216Metric
R35, R36: 100k; R_1206_3216Metric
R39, R42: R_Small; R_1206_3216Metric
R43: 120; R_1206_3216Metric
U1: BME280
U2: FDS6675BZ1; FDS6675; Manufacturer Part FDS6675BZ; LCSC Part Name 1个P沟道 耐压:30V 电流:11A
U3: Teensy4.1; Teensy41
U4: ADS1220xPW; TSSOP-16_4.4x5mm_P0.65mm
U5: LT3045xMSE; MSOP-12-1EP_3x4.039mm_P0.65mm_EP1.651x2.845mm
U6: XL1509-3.3; SOIC-8_3.9x4.9mm_P1.27mm
U7: TXS0108EPW; TSSOP-20_4.4x6.5mm_P0.65mm
U8: XL1509-5.0; SOIC-8_3.9x4.9mm_P1.27mm
U9: LM393; SOIC-8_3.9x4.9mm_P1.27mm
U10: SN65HVD230; SOIC-8_3.9x4.9mm_P1.27mm

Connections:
+3.3V: C1.2, C2.1, C7.2, C15.1, C16.2, C17.1, C19.2, C22.2, C23.1, IC1.10 (VDDPL), IC1.11 (VDDL), J2.2 (3.3V), J5.2 (VCC), J8.2 (3.3V), L1.2, R5.1, R7.1, R18.1, R20.1, R21.1, R22.1, R31.1, R32.1, R40.1, U1.2 (CSB), U1.6 (VDDIO), U1.8 (VDD), U4.13 (DVDD), U6.3 (FB), U7.2 (VCCA), U10.3 (VCC)
+5V: C26.1, C27.1, J3.2 (VCC), J4.2 (5V), L2.2, R25.2, R27.2, U3.48 (VIN), U7.19 (VCCB), U8.3 (FB), U9.8 (V+)
+5VA: C11.2, C13.2, C14.1, J6.2 (5V), NT2.2, R19.2, U4.12 (AVDD), U5.10 (OUTS), U5.11 (OUT), U5.12 (OUT)
+12V: C8.1, C9.2, C12.1, C20.1, C24.1, D1.1 (K), J7.3 (VCC), U2.1 (S), U2.2 (S), U2.3 (S), U5.1 (IN), U5.2 (IN), U5.3 (IN), U5.4 (EN/UV), U6.1 (VIN), U8.1 (VIN)
AIN0: J6.4 (AIN0), R2.1
AIN1: J6.3 (AIN1), R1.1
CAN_RX: C32.1, U3.45 (23_A9_CRX1_MCLK1), U10.4 (R)
CAN_TX: U3.44 (22_A8_CTX1), U10.1 (D)
CS: R17.2, U3.12 (10_CS_MQSR)
CS_L: IC1.15 (~CS), U3.2 (0_RX1_CRX2_CS1)
DRDY_L: IC1.16 (~INT), U3.7 (5_IN2)
DS18B20: J8.3 (SIGNAL), R40.2, U3.37 (15_A1_RX3_SPDIF_IN)
E+: NT2.1, R8.2
E-: NT1.1, R9.1
ENC_A: C25.1, J7.5 (A), R22.2, R24.1
ENC_B: C21.1, J7.4 (B), R21.2, R23.1
GND: C1.1, C2.2, C3.2, C5.2, C7.1, C8.2, C9.1, C10.2, C11.1, C12.2, C13.1, C14.2, C15.2, C16.1, C17.2, C18.1, C19.1, C20.2, C21.2, C22.1, C23.2, C24.2, C25.2, C26.2, C27.2, C32.2, D2.1 (K), D3.2 (A), D4.2 (A), IC1.9 (GNDL), J1.2 (IN-), J2.1 (GND), J3.1 (GND), J4.1 (GND), J5.1 (GND), J6.1 (SHIELD), J6.5 (GND), J7.1 (SHIELD), J7.2 (GND), J8.1 (GND), J11.1 (GND), JP1.1 (A), NT1.2, R6.2, R10.2, R11.1, R15.1, R26.2, R28.2, R37.2, U1.1 (GND), U1.5 (SDO), U1.7 (GND), U3.1 (GND), U3.34 (GND), U3.47 (GND), U4.3 (CLK), U4.4 (DGND), U4.5 (AVSS), U5.9 (GND), U5.13 (GND), U6.4 (~EN), U6.5 (GND), U6.6 (GND), U6.7 (GND), U6.8 (GND), U7.11 (GND), U8.4 (~EN), U8.5 (GND), U8.6 (GND), U8.7 (GND), U8.8 (GND), U9.4 (V-), U10.2 (GND)
GND1: C28.1, C29.2, C30.1, C31.2, C33.2, C34.2, D5.2 (A), D6.2 (A), IC1.2 (AGND), IC1.8 (GNDF), J9.1 (AGND), J10.1 (AGND), R35.2, R36.2, R38.1, R39.1
HALL_SIGNAL: J2.3 (SIGNAL), U3.16 (24_A10_TX6_SCL2)
INT: R14.1, U3.33 (41_A17)
LCELL_DAT: U3.11 (9_OUT1C), U7.7 (A6)
LCELL_SCK: U3.10 (8_TX2_IN1), U7.8 (A7)
MISO: R13.2, U3.14 (12_MISO_MQSL)
MISO_L: IC1.12 (SDO), U3.3 (1_TX1_CTX2_MISO1)
MOSI: R16.2, U3.13 (11_MOSI_CTX1)
MOSI_L: IC1.13 (SDI), U3.18 (26_A12_MOSI1)
unnamed: D1.2 (A), R6.1, U2.4 (G)
unnamed: D2.2 (A), R18.2
unnamed: D3.1 (K), L1.1, U6.2 (OUT)
unnamed: D4.1 (K), L2.1, U8.2 (OUT)
unnamed: C33.1, D5.1 (K), IC1.4 (AIN2), R38.2, R41.2
unnamed: C34.1, D6.1 (K), IC1.3 (AIN1), R39.2, R42.2
unnamed: IC1.5 (AIN3), R36.1
unnamed: IC1.6 (AIN4), R35.1
unnamed: C28.2, C30.2, IC1.1 (REF)
unnamed: C29.1, C31.1, IC1.7 (VDDF)
unnamed: J1.1 (IN+), U2.5 (D), U2.6 (D), U2.7 (D), U2.8 (D)
unnamed: J3.4 (CLK), U7.13 (B7)
unnamed: J3.3 (DAT), U7.14 (B6)
unnamed: J4.3 (PWM), U7.12 (B8)
unnamed: J9.2 (AIN2), R41.1
unnamed: J10.2 (AIN1), R42.1
unnamed: J11.2 (CAN-H), JP2.1 (A), U10.7 (CANH)
unnamed: J11.3 (CAN-L), R43.2, U10.6 (CANL)
unnamed: JP1.2 (B), R37.1, U10.8 (Rs)
unnamed: JP2.2 (B), R43.1
unnamed: R23.2, R30.2, U9.5 (+)
unnamed: R24.2, R29.2, U9.3 (+)
unnamed: R25.1, R26.1, U9.2 (-)
unnamed: R27.1, R28.1, U9.6 (-)
unnamed: R29.1, R31.2, R33.1, U9.1
unnamed: R30.1, R32.2, R34.1, U9.7
unnamed: C3.1, C4.1, R2.2, U4.11 (AIN0/REFP1)
unnamed: C4.2, C5.1, R1.2, U4.10 (AIN1)
unnamed: R16.1, U4.16 (DIN)
unnamed: R13.1, U4.15 (DOUT/~DRDY)
unnamed: C6.2, R9.2, U4.8 (REFN0)
unnamed: C6.1, R8.1, U4.9 (REFP0)
unnamed: R12.1, U4.1 (SCLK)
unnamed: R17.1, U4.2 (~CS)
unnamed: R14.2, U4.14 (~DRDY)
unnamed: R10.1, U5.6 (ILIM)
unnamed: R15.2, R19.1, U5.7 (PGFB)
unnamed: C10.1, R11.2, U5.8 (SET)
unnamed: C18.2, R20.2, U7.10 (OE)
PWM: U3.6 (4_BCLK2), U7.9 (A8)
SCK: R12.2, U3.35 (13_SCK_LED)
SCL: J5.4 (SCL), U3.41 (19_A5_SCL)
SCLK_L: IC1.14 (SCLK), U3.19 (27_A13_SCK1)
SCL_1: R5.2, U1.4 (SCK), U3.38 (16_A2_RX4_SCL1)
SDA: J5.3 (SDA), U3.40 (18_A4_SDA)
SDA_1: R7.2, U1.3 (SDI), U3.39 (17_A3_TX4_SDA1)
ST_A: R33.2, U3.5 (3_LRCLK2)
ST_B: R34.2, U3.4 (2_OUT2)

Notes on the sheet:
Hall Current Sensor
ADS1220 - Load Cell ADC
Load Cell
LM393 - Schmitt Trigger
DS18B20 - DynoPower Temperature Sensor
Isolated 4 Channel ADC
SH65HVD230 - CAN Bus
5V DC Regulator
Infrared temperature sensor connector (Pull-up resistors in the sensor board)
Level shifter / PWM / HX711 - Load Cell ADC
3.3V DC Regulator
Encoder Connector
Teensy 4.1 - MCU
Reverse Polarity Protection
BME280 - Temperature & Humidity Sensor
LT3045 - LDO
On Board LED

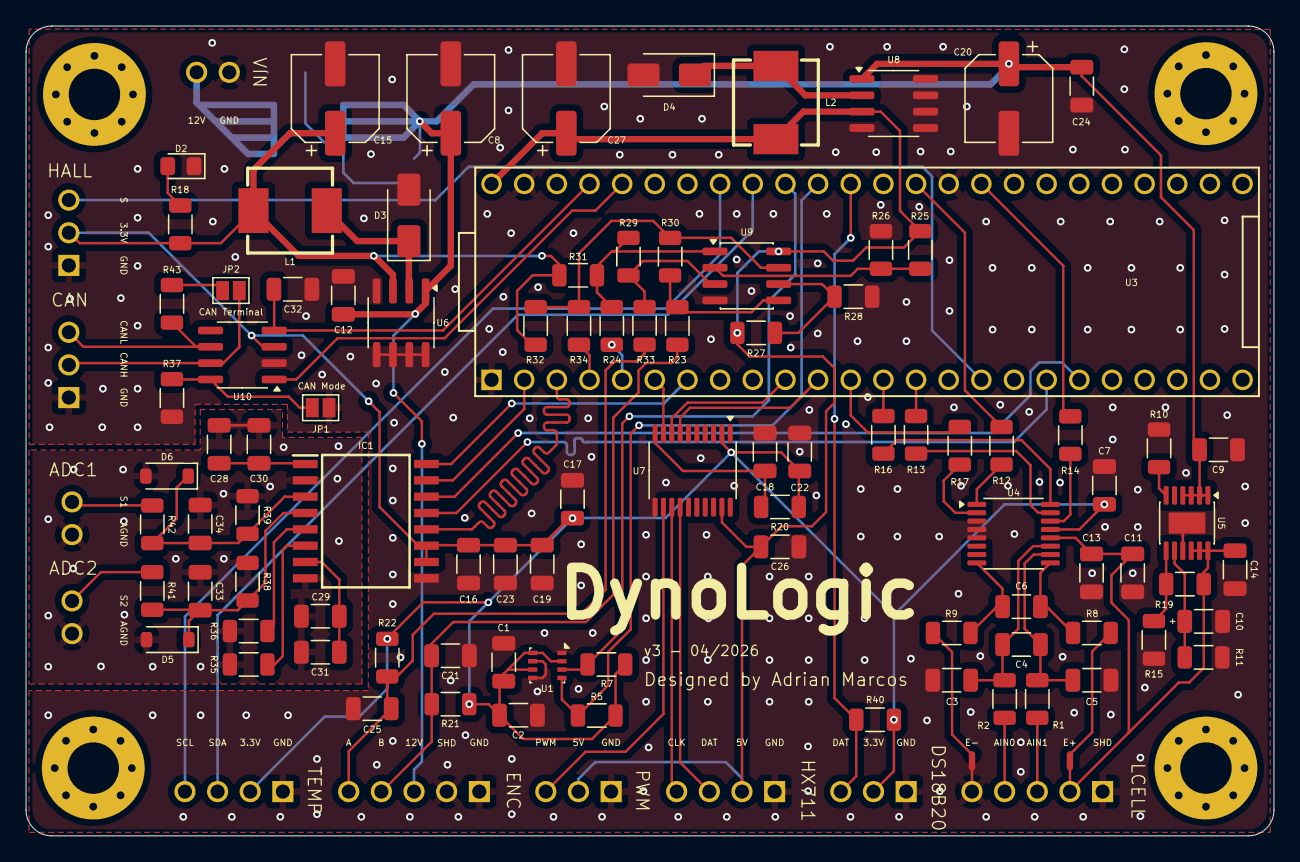
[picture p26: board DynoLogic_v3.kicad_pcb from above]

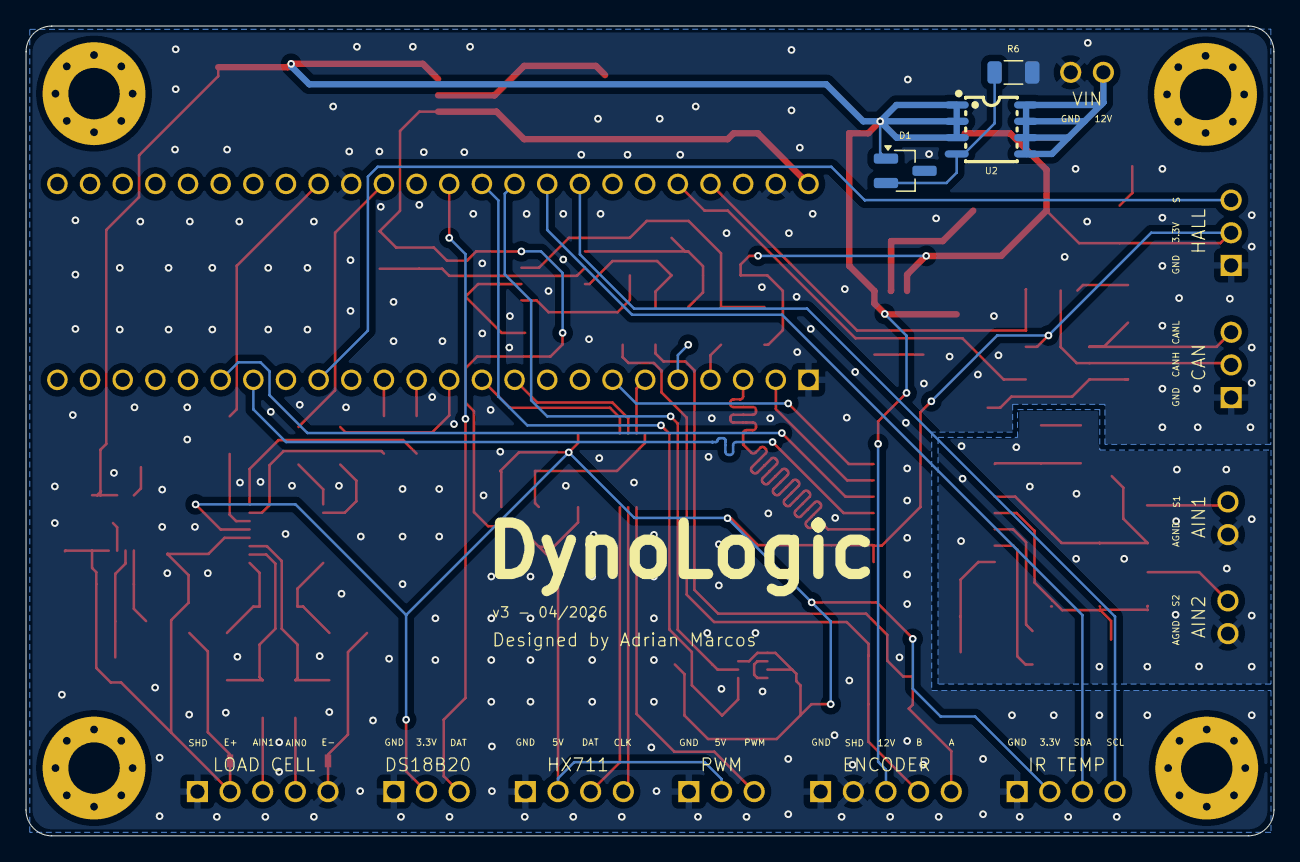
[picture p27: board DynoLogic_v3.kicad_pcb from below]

Board: 2 copper layers, 97.1 x 63.0 mm, 113 parts (3 on the bottom side), 74 nets.

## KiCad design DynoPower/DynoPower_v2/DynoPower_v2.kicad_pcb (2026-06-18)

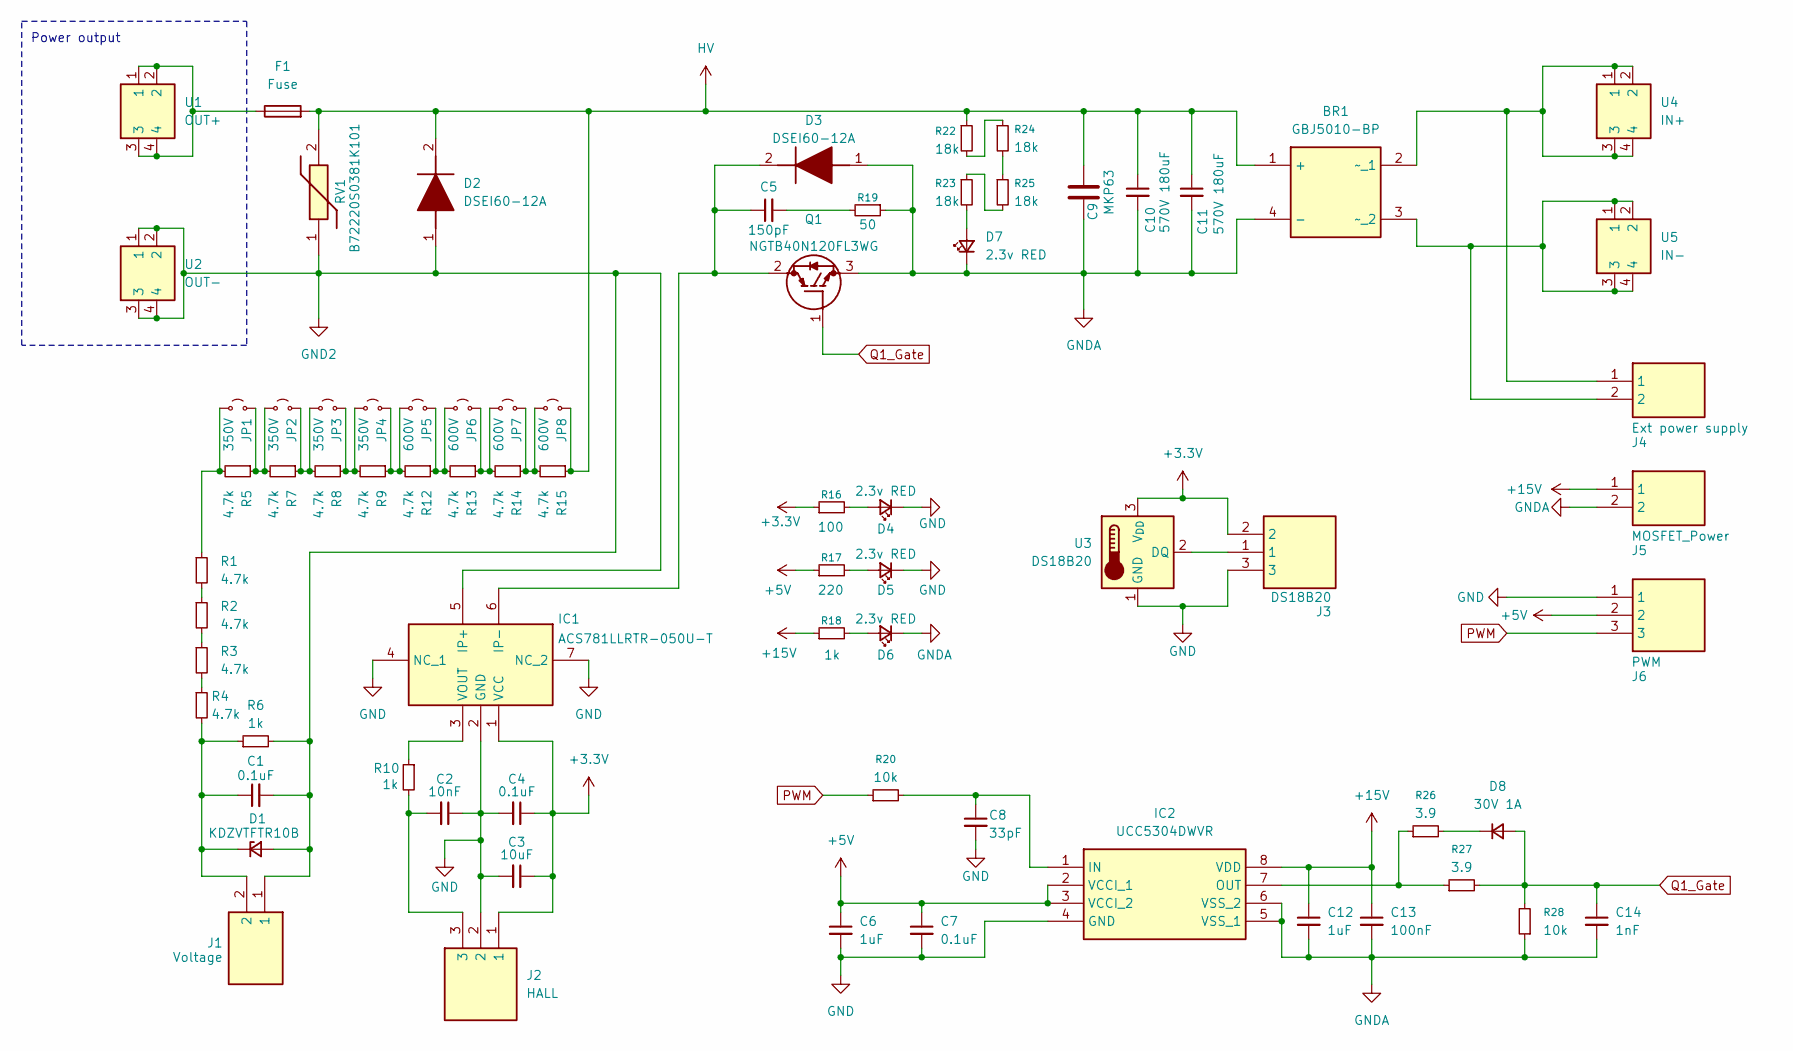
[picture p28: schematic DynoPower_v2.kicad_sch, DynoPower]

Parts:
BR1: GBJ5010-BP; GBJ5010; Mouser Part Number 833-GBJ5010-BP
C1, C4: 0.1uF; C_1206_3216Metric
C2: 10nF; C_1206_3216Metric
C3: 10uF; C_1206_3216Metric
C5: 150pF; C_1206_3216Metric_Pad1.33x1.80mm_HandSolder
C6, C12: 1uF; C_1206_3216Metric_Pad1.33x1.80mm_HandSolder
C7: 0.1uF; C_1206_3216Metric_Pad1.33x1.80mm_HandSolder
C8: 33pF; C_1206_3216Metric_Pad1.33x1.80mm_HandSolder
C9: MKP63; KNB2520
C10, C11: 570V 180uF; Capacitor
C13: 100nF; C_1206_3216Metric_Pad1.33x1.80mm_HandSolder
C14: 1nF; C_0603_1608Metric_Pad1.08x0.95mm_HandSolder
D1: KDZVTFTR10B; D_SOD-123F
D2, D3: DSEI60-12A; Mouser Part Number 747-DSEI60-12A
D4, D5, D6, D7: 2.3v RED; D_0805_2012Metric_Pad1.15x1.40mm_HandSolder
D8: 30V 1A; D_SOD-123
F1: Fuse; Fuseholder_Clip-6.3x32mm_Littelfuse_102_122_Inline_P34.21x7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
IC1: ACS781LLRTR-050U-T; ACS780LLRTR050BT; Mouser Part Number 250-781LLRTR100BT
IC2: UCC5304DWVR; Mouser Part Number 595-UCC5304DWVR
J1: Voltage; Connector_2pin; Mouser Part Number 538-39773-0002
J2: HALL; Connector_3pin; Mouser Part Number 538-39773-0003
J3: DS18B20; Connector_3pin; Mouser Part Number 538-39773-0003
J4: Ext power supply; Connector_2pin; Mouser Part Number 538-39773-0002
J5: MOSFET_Power; Connector_2pin; Mouser Part Number 538-39773-0002
J6: PWM; Connector_3pin; Mouser Part Number 538-39773-0003
JP1, JP2, JP3, JP4: 350V; SolderJumper-2_P1.3mm_Open_RoundedPad1.0x1.5mm
JP5, JP6, JP7, JP8: 600V; SolderJumper-2_P1.3mm_Open_RoundedPad1.0x1.5mm
Q1: NGTB40N120FL3WG; Mouser Part Number 863-NGTB40N120FL3WG
R1, R2, R3, R4, R5, R7, R8, R9, R12, R13, R14, R15: 4.7k; R_1206_3216Metric
R6, R10: 1k; R_1206_3216Metric
R16: 100; R_1206_3216Metric
R17: 220; R_1206_3216Metric_Pad1.30x1.75mm_HandSolder
R18: 1k; R_1206_3216Metric_Pad1.30x1.75mm_HandSolder
R19: 50; R_1206_3216Metric_Pad1.30x1.75mm_HandSolder
R20, R28: 10k; R_1206_3216Metric_Pad1.30x1.75mm_HandSolder
R22, R23, R24, R25: 18k; R_2512_6332Metric_Pad1.40x3.35mm_HandSolder
R26, R27: 3.9; R_2512_6332Metric_Pad1.40x3.35mm_HandSolder
RV1: B72220S0381K101; Mouser Part Number 871-B72220S381K101
U1: OUT+; PowerTerminal_S
U2: OUT-; PowerTerminal_S
U3: DS18B20; TO-92_Inline
U4: IN+; PowerTerminal_S
U5: IN-; PowerTerminal_S

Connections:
+3.3V: C3.1, C4.1, IC1.1 (VCC), J2.1, J3.2, R16.1, U3.3 (V_{DD})
+5V: C6.1, C7.1, IC2.2 (VCCI_1), IC2.3 (VCCI_2), J6.2, R17.1
+15V: C12.1, C13.1, IC2.8 (VDD), J5.1, R18.1
GND: C2.1, C3.2, C4.2, C6.2, C7.2, C8.2, D4.1 (K), D5.1 (K), IC1.2 (GND), IC1.4 (NC_1), IC1.7 (NC_2), IC2.4 (GND), J2.2, J3.3, J6.1, U3.1 (GND)
GND2: C1.2, D1.2 (A), D2.1 (A), IC1.5 (IP+), J1.1, R6.2, RV1.1, U2.1, U2.2, U2.3, U2.4
GNDA: BR1.4 (-), C9.2, C10.2, C11.2, C12.2, C13.2, C14.2, D3.1 (A), D6.1 (K), D7.1 (K), IC2.5 (VSS_1), IC2.6 (VSS_2), J5.2, Q1.3 (E), R19.1, R28.1
HV: BR1.1 (+), C9.1, C10.1, C11.1, D2.2 (K), F1.2, JP8.2 (B), R15.1, R22.1, RV1.2
unnamed: BR1.2 (~_1), J4.1, U4.1, U4.2, U4.3, U4.4
unnamed: BR1.3 (~_2), J4.2, U5.1, U5.2, U5.3, U5.4
unnamed: C2.2, J2.3, R10.2
unnamed: C5.2, R19.2
unnamed: C1.1, D1.1 (K), J1.2, R4.2, R6.1
unnamed: C5.1, D3.2 (K), IC1.6 (IP-), Q1.2 (C)
unnamed: D4.2 (A), R16.2
unnamed: D5.2 (A), R17.2
unnamed: D6.2 (A), R18.2
unnamed: D7.2 (A), R23.2
unnamed: D8.1 (K), R26.2
unnamed: F1.1, U1.1, U1.2, U1.3, U1.4
unnamed: IC1.3 (VOUT), R10.1
unnamed: C8.1, IC2.1 (IN), R20.2
unnamed: IC2.7 (OUT), R26.1, R27.1
unnamed: JP1.1 (A), R1.1, R5.2
unnamed: JP1.2 (B), JP2.1 (A), R5.1, R7.2
unnamed: JP2.2 (B), JP3.1 (A), R7.1, R8.2
unnamed: JP3.2 (B), JP4.1 (A), R8.1, R9.2
unnamed: JP4.2 (B), JP5.1 (A), R9.1, R12.2
unnamed: JP5.2 (B), JP6.1 (A), R12.1, R13.2
unnamed: JP6.2 (B), JP7.1 (A), R13.1, R14.2
unnamed: JP7.2 (B), JP8.1 (A), R14.1, R15.2
unnamed: R1.2, R2.1
unnamed: R2.2, R3.1
unnamed: R3.2, R4.1
unnamed: R22.2, R24.1
unnamed: R23.1, R25.2
unnamed: R24.2, R25.1
unnamed: J3.1, U3.2 (DQ)
PWM: J6.3, R20.1
Q1_Gate: C14.1, D8.2 (A), Q1.1 (G), R27.2, R28.2

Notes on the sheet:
Power output

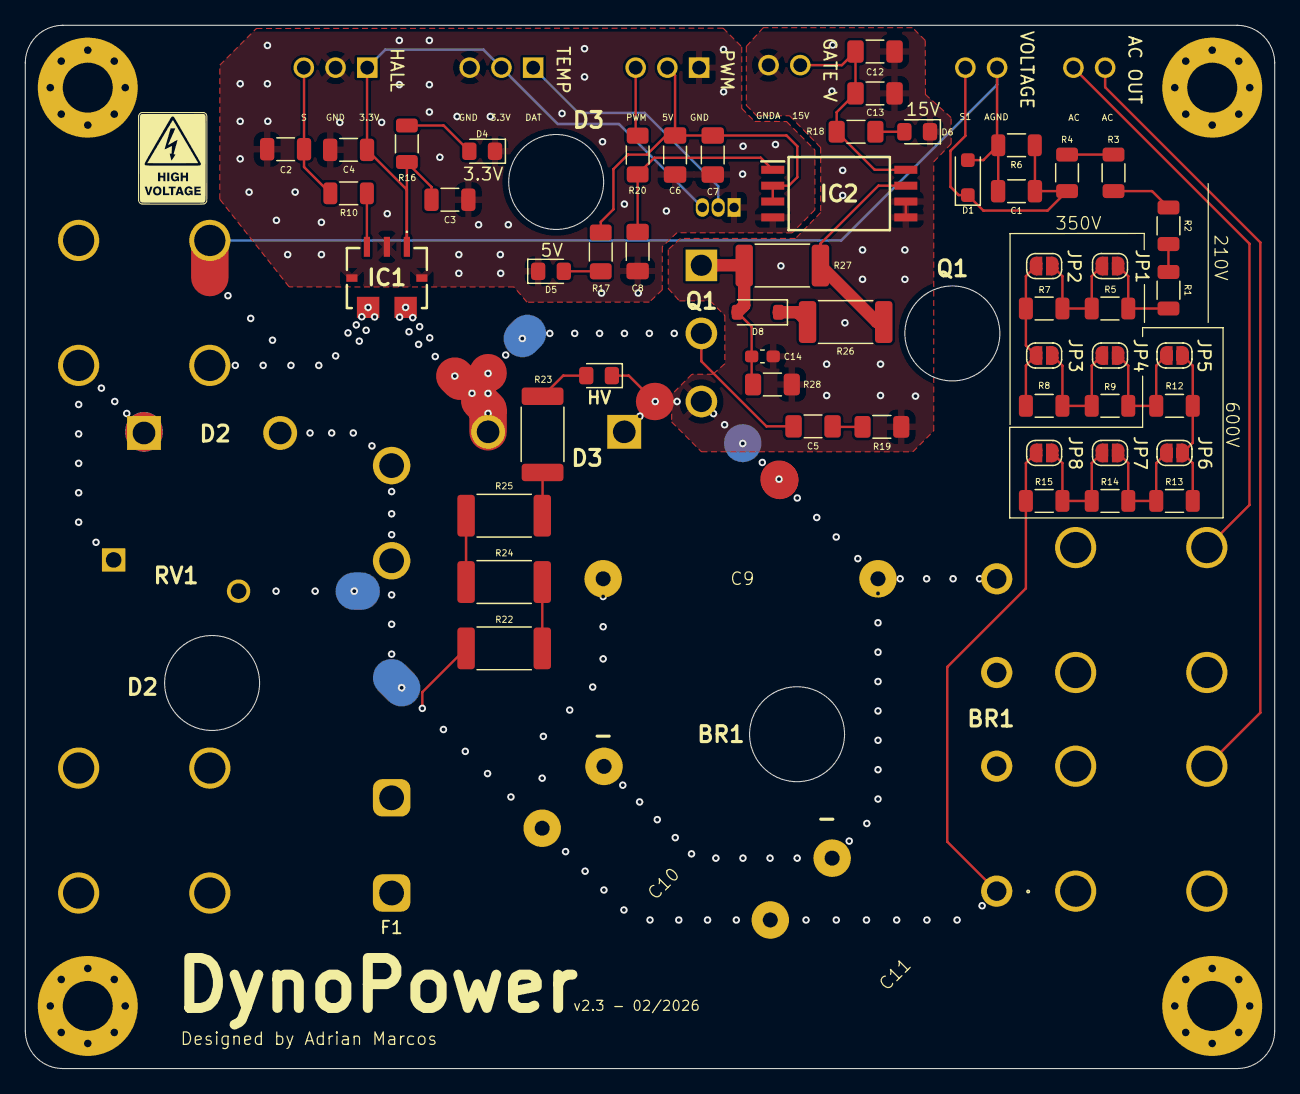
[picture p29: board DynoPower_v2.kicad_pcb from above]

Board: 2 copper layers, 100.0 x 83.5 mm, 73 parts (1 on the bottom side), 39 nets.

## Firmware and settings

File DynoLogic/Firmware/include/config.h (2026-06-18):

// config.h - System configuration parameters

#ifndef CONFIG_H
#define CONFIG_H

// SERIAL
#define SERIAL_PORT Serial                    // Primary serial interface for debug/output
#define SERIAL_SPEED 500000                   // Baud rate [bps]

// DEBUG OUTPUT
//#define ENABLE_DEBUG_OUTPUT

#ifdef ENABLE_DEBUG_OUTPUT
// Debug macros - compile to nothing when debug is disabled
#define DEBUG_PRINT(...)  if(SERIAL_PORT){ SERIAL_PORT.print(__VA_ARGS__); }
#define DEBUG_PRINTLN(...) if(SERIAL_PORT){ SERIAL_PORT.println(__VA_ARGS__); }
#else
#define DEBUG_PRINT(...)
#define DEBUG_PRINTLN(...)
#endif

// EDDY CURRENT BRAKE PWM
#define DEFAULT_PWM_FREQUENCY 1000            // PWM frequency [Hz] - 1kHz for smooth brake control
#define PWM_START_DUTY 0                      // Initial PWM duty cycle at startup
#define DEFAULT_MIN_PWM_OUTPUT 0              // Minimum PWM value (safety floor)
#define DEFAULT_MAX_PWM_OUTPUT 330            // Maximum PWM value (safety ceiling)

// CAN BUS
#define CAN_INTERFACE ACAN_T4::can1           // CAN controller instance
#define CAN_SPEED 500000                      // CAN bus speed [500 kbps]

// VOLTAGE MEASUREMENT (MAX22530 ADC)
// UNUSED
#define MAX22530_SPI &SPI                     // SPI interface for MAX22530
#define MAX22530_SPI_SPEED 1000000            // SPI clock frequency [1 MHz]

// ENCODER (SPEED MEASUREMENT)
#define ENC_PPR 50                            // Pulses per revolution (base resolution)
#define ENC_REVERSE_DIRECTION 1               // Reverse quadrature sign so normal dyno rotation reports positive RPM
#define STOP_TIMEOUT_MS 200                   // Timeout [ms] to detect stopped condition

// PID CONTROL LOOP
#define PID_FREQUENCY 1000                    // PID update interval [us] = 1ms (1000Hz)
#define PWM_FREQUENCY 1000

// MAIN LOOP TIMING INTERVALS
#define SECURITY_CHECK_INTERVAL 4000          // Security check interval [ms]

// LOW-PASS FILTER DEFAULTS
#define LOW_PASS_FILTER_SPEED_FREQ 20.0       // Speed filter cutoff [Hz] (per-stage)
#define LOW_PASS_FILTER_TORQUE_FREQ 15.0      // Torque filter cutoff [Hz] (per-stage)
#define LOW_PASS_FILTER_ACC_FREQ 10.0         // Acceleration filter cutoff [Hz] (per-stage)
#define LOW_PASS_FILTER_OUTPUT_FREQ 20.0      // PID output filter cutoff [Hz]

// Cascaded IIR stage counts (serial first-order sections, exp-form coefficient).
#define SPEED_LPF_STAGES 1
#define TORQUE_LPF_STAGES 4
#define ACCEL_LPF_STAGES 2

// DYNO OPERATIONAL LIMITS
#define DEFAULT_MINIMUM_SPEED 500             // Minimum operating speed [RPM]
#define DEFAULT_MAXIMUM_SPEED 4500            // Maximum operating speed [RPM]

// LOAD CELL SELECTION
//#define USE_HX711_LOAD_CELL                 // HX711 external load cell (alternative)
#define USE_ADS1220_LOAD_CELL                 // ADS1220 internal load cell (default)

// PHYSICAL CONSTANTS
#define GRAVITY 9.80665                       // Standard gravity [m/s^2] for torque calculations

// HALL EFFECT CURRENT SENSOR
#define ADC_MAX 4096.0f                       // ADC maximum value
#define ADC_REF_V 3.3f                        // ADC reference voltage [V]
#define V_OFFSET 0.33f                        // Zero-current output [V]
#define SENSITIVITY 0.0396f                   // V per Amp

#endif // CONFIG_H

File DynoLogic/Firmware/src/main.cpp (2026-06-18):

// main.cpp - Main control loop and system initialization

#include <HX711.h>
#include <imxrt.h>
#include <Wire.h>
#include <Arduino.h>
#include <ACAN_T4.h>
#include <OneWire.h>
#include <Adafruit_BME280.h>
#include <Protocentral_ADS1220.h>
#undef MODE_NORMAL   // clashes with Adafruit_BME280::MODE_NORMAL enum value
#undef START         // clashes with can.h START symbol
#include "QuickPID.h"
#include <MAX22530.h>
#include <Adafruit_MLX90614.h>
#include <DallasTemperature.h>
#include <NonBlockingDallas.h>
#include <TeensyThreads.h>   // Background thread for DS18B20 OneWire polling and BME280 I2C polling

// Local headers
#include "can.h"
#include "main.h"
#include "pins.h"
#include "config.h"
#include "encoder.h"
#include "messages.h"
#include "utilities.h"

// GLOBAL SYSTEM STATE
Status status;                       // Real-time measurements and system state
Configuration config;                // Active configuration parameters
Dynamic_config_static static_config; // Fixed dynamic testing parameters
volatile TimeControl time_control;   // Multi-rate timing flags

volatile uint32_t counter_1ms = 0;
volatile uint32_t counter_10ms = 0;
volatile uint32_t counter_100ms = 0;
volatile uint32_t counter_500ms = 0;
volatile uint32_t counter_1s = 0;

// DS18B20 BACKGROUND THREAD
static int ds18b20_thread_id = -1;          // Thread handle (-1 = not started)
static Threads::Mutex ds18b20_mutex;         // Guards status.env_temperature

// BME280 BACKGROUND THREAD
static int bme280_thread_id = -1;            // Thread handle (-1 = not started)
static Threads::Mutex bme280_mutex;          // Guards status.temperature/humidity

// SIGNAL FILTERING
CascadedLowPassFilter torqueFilter;   // Cascaded variable-rate torque filter (commercial-style)
CascadedLowPassFilter speedFilter;    // Cascaded variable-rate speed filter (commercial-style)
CascadedLowPassFilter accFilter;      // Cascaded variable-rate acceleration filter (commercial-style)
LowPassFilter outputFilter;           // Control output smoothing filter

// DATA CONVERSION
Float_converter float_converter; // Float/byte union for CAN protocol

// ADS1220 DRDY INTERRUPT FLAG
#if defined(USE_ADS1220_LOAD_CELL)
volatile bool ads_drdy_ready = false;

/**
 * ADS1220 DRDY interrupt handler
 */
void ads_drdy_isr()
{
    ads_drdy_ready = true;
}
#endif

// HALL SENSOR OVERSAMPLING
HallSensorAverager hallAverager;  // Global instance

// HARDWARE PERIPHERAL INSTANCES
Adafruit_BME280 bme;                                     // BME280 environmental sensor (Wire1)
MAX22530 adc(MAX22530_CS_PIN, MAX22530_SPI);             // Voltage ADC (SPI)
OneWire oneWire(ONE_WIRE_BUS);                           // DS18B20 OneWire bus
DallasTemperature dallasTemp(&oneWire);                  // DS18B20 temperature
NonBlockingDallas temperatureSensors(&dallasTemp);       // DS18B20 non-blocking
ACAN_T4_Settings can_settings(CAN_SPEED);                // 500kbps CAN config
Adafruit_MLX90614 mlx = Adafruit_MLX90614();             // IR brake temperature

// Load cell ADC (compile-time selection)
#if defined(USE_HX711_LOAD_CELL)
HX711 hx711;                                             // External HX711 ADC
#elif defined(USE_ADS1220_LOAD_CELL)
Protocentral_ADS1220 ads_chip;                           // Internal ADS1220 (uses default SPI)
#else
#define USE_HX711_LOAD_CELL
HX711 hx711;
#endif

// DYNAMIC TESTING STATE VARIABLES
float limit_speed, dynamic_brake, dyno_baseline_load;     // Dynamic mode setpoints
volatile uint32_t dyno_stable_enter_ms = 0;               // Stability timer entry
volatile uint32_t dyno_hold_start_ms = 0;                 // Hold phase timer
bool dyno_baseline_valid = false;                         // Baseline torque captured

// PID CONTROLLERS
// Torque PID - Maintains constant torque (Nm) via load cell feedback
QuickPID torquePID((float *)&status.current_torque,
                   &status.pid_output,
                   &config.mode.value,
                   config.torque_pid.kp,
                   config.torque_pid.ki,
                   config.torque_pid.kd,
                   QuickPID::pMode::pOnErrorMeas,
                   QuickPID::dMode::dOnMeas,
                   QuickPID::iAwMode::iAwClamp,
                   QuickPID::Action::direct);

// Speed PID - Maintains constant RPM via encoder feedback
QuickPID speedPID((float *)&status.current_speed,
                  &status.pid_output,
                  &config.mode.value,
                  config.speed_pid.kp,
                  config.speed_pid.ki,
                  config.speed_pid.kd,
                  QuickPID::pMode::pOnErrorMeas,
                  QuickPID::dMode::dOnMeas,
                  QuickPID::iAwMode::iAwClamp,
                  QuickPID::Action::reverse);

// Speed Limit PID - Safety override to prevent overspeed
QuickPID speedLimitPID((float *)&status.current_speed,
                       &status.pid_output,
                       &limit_speed,
                       config.speed_pid.kp,
                       config.speed_pid.ki,
                       config.speed_pid.kd,
                       QuickPID::pMode::pOnErrorMeas,
                       QuickPID::dMode::dOnMeas,
                       QuickPID::iAwMode::iAwClamp,
                       QuickPID::Action::reverse);

// Dynamic PID - Controls acceleration rate (RPM/s)
QuickPID dynamicPID((float *)&status.current_acc,
                    &status.pid_output,
                    &config.mode.value,
                    config.dynamic_pid.kp,
                    config.dynamic_pid.ki,
                    config.dynamic_pid.kd,
                    QuickPID::pMode::pOnErrorMeas,
                    QuickPID::dMode::dOnMeas,
                    QuickPID::iAwMode::iAwClamp,
                    QuickPID::Action::reverse);

// Brake Dynamic PID - Controls deceleration rate
QuickPID brakeDynamicPID((float *)&status.current_acc,
                         &status.pid_output,
                         &dynamic_brake,
                         config.dynamic_pid.kp,
                         config.dynamic_pid.ki,
                         config.dynamic_pid.kd,
                         QuickPID::pMode::pOnMeas,
                         QuickPID::dMode::dOnMeas,
                         QuickPID::iAwMode::iAwClamp,
                         QuickPID::Action::reverse);

// TIMING VARIABLES
unsigned long last_security_time_check = 0;  // Connection watchdog timer

/**
 * DS18B20 background thread
 */
void ds18b20_thread_fn()
{
    while (true)
    {
        temperatureSensors.update();
        threads.delay(5);
    }
}

/**
 * BME280 background thread
 */
void bme280_thread_fn()
{
    while (true)
    {
        const float temp_c = bme.readTemperature(); // I2C read, blocks this thread only
        const float hum_pct = bme.readHumidity();

        if (!isnan(temp_c) && !isnan(hum_pct))
        {
            Threads::Scope lock(bme280_mutex);
            status.temperature = temp_c;
            status.humidity = hum_pct;
        }

        threads.delay(1000);
    }
}

static void enforce_disconnect_failsafe(void)
{
    if (status.connected)
    {
        return;
    }

    // Force safe state immediately when CAN link is lost.
    status.status = STOPPED;
    status.info = INFO_MSG_STOPPED;
    status.manual_pwm_enabled = false;
    status.pid_output = 0.0f;
    status.pwm_value = 0.0f;

    torquePID.SetMode(QuickPID::Control::manual);
    speedPID.SetMode(QuickPID::Control::manual);
    dynamicPID.SetMode(QuickPID::Control::manual);
    brakeDynamicPID.SetMode(QuickPID::Control::manual);
    speedLimitPID.SetMode(QuickPID::Control::manual);

    // Bypass set_pwm() clamp path so output is truly off.
    outputFilter.y_prev = 0.0f;
    outputFilter.timestamp_prev = 0;
    setDutyPercent(0.0f);
}

// INTERRUPT SERVICE ROUTINES

/**
 * 1ms timer interrupt handler
 *
 * Generates multi-rate timing flags for task scheduling:
 * - 1ms: PID control (1000Hz)
 * - 10ms: Real-time data transmission (100Hz)
 * - 100ms: CAN heartbeat, electrical data (10Hz)
 * - 500ms: System status broadcast (2Hz)
 * - 1s: Temperature sensors, config timeout (1Hz)
 * - 5s: Maintenance tasks (0.2Hz)
 */
void timer_1ms_isr(void)
{
    // Queue 1ms work for the main loop
    if (time_control.pending_1ms < 255) time_control.pending_1ms++;
    counter_1ms++;

    // 10ms flag - every 10 × 1ms
    if (counter_1ms >= 10)
    {
        if (time_control.pending_10ms < 255) time_control.pending_10ms++;
        counter_1ms = 0;
        counter_10ms++;
    }

    // 100ms flag - every 10 × 10ms
    if (counter_10ms >= 10)
    {
        if (time_control.pending_100ms < 255) time_control.pending_100ms++;
        counter_10ms = 0;
        counter_100ms++;
    }

    // 500ms flag - every 5 × 100ms
    if (counter_100ms >= 5)
    {
        if (time_control.pending_500ms < 255) time_control.pending_500ms++;
        counter_100ms = 0;
        counter_500ms++;
    }

    // 1s flag - every 2 × 500ms
    if (counter_500ms >= 2)
    {
        if (time_control.pending_1s < 255) time_control.pending_1s++;
        counter_500ms = 0;
        counter_1s++;
    }

    // 5s flag - every 5 × 1s
    if (counter_1s >= 5)
    {
        if (time_control.pending_5s < 255) time_control.pending_5s++;
        counter_1s = 0;
    }
}

// 1ms interval timer (Teensy 4.1 hardware timer)
IntervalTimer timer1ms;

// FLEXPWM INTERRUPT (HALL SENSOR ADC SYNCHRONIZATION)

/**
 * FlexPWM Hardware Interrupt
 */
FASTRUN void flexpwm2_0_isr(void)
{
    // Clear the reload flag to acknowledge the interrupt
    IMXRT_FLEXPWM2.SM[0].STS = FLEXPWM_SMSTS_RF;

    // Call our synchronously-timed sampling function
    sample_hall_sensor_sync(hallAverager);
    
    asm("dsb"); // memory barrier
}

// INIT FUNCTION

/**
 * System initialization
 *
 * Called once at startup. Initializes all hardware in sequence:
 * 1. Serial communication (debug output)
 * 2. PWM output for brake control
 * 3. Data structures (default values)
 * 4. PID controllers (limits and timing)
 * 5. Interrupt timer (1ms for multi-rate scheduling)
 * 6. CAN communication
 * 7. Encoder (speed measurement)
 * 8. Load cell (torque sensor)
 * 9. External ADC (voltage measurement)
 * 10. IR temperature sensor (brake monitoring)
 * 11. DS18B20 ambient temperature
 * 12. Hall sensor (current measurement)
 * 13. Environmental sensor (BME280)
 */
void setup(void)
{
// Serial communication
#ifdef ENABLE_DEBUG_OUTPUT
    SERIAL_PORT.begin(SERIAL_SPEED); // 500kbps for fast debug output
#endif
    delay(5000); // Startup delay for debugging

    DEBUG_PRINT("[+] Expected C++ struct size: ");
    DEBUG_PRINTLN(sizeof(Configuration));

    // Core system initialization
    init_pwm();             // Eddy current brake PWM

    // Configure FlexPWM hardware trigger for ADC synchronization
    // Attach to FlexPWM2 Submodule 0 (controls Pin 4)
    attachInterruptVector(IRQ_FLEXPWM2_0, flexpwm2_0_isr);
    NVIC_ENABLE_IRQ(IRQ_FLEXPWM2_0);
    IMXRT_FLEXPWM2.SM[0].INTEN |= FLEXPWM_SMINTEN_RIE; // Enable Reload Interrupt

    init_data_structures(); // System state and configuration
    init_pid();             // PID controllers
    init_interrupts();      // 1ms multi-rate timer

    // Hardware peripherals
    init_can();          // CAN bus (500kbps)
    init_encoder();      // Rotary encoder (quadrature)

    // Load cell (compile-time selection)
    #if defined(USE_HX711_LOAD_CELL)
    init_hx711();                               // HX711 external ADC
    #elif defined(USE_ADS1220_LOAD_CELL)
    init_internal_lcell();                      // ADS1220 internal ADC
    #endif

    // init_external_adc(); // MAX22530 SPI ADC (voltage) — UNUSED
    init_i2c_temp();     // MLX90614 IR sensor (brake temp)
    init_ds18b20();      // DS18B20 ambient temp
    init_hall();         // Hall sensor (current)
    init_env_temp();     // BME280 environmental (T + RH on Wire1)

    // Start DS18B20 background thread
    ds18b20_thread_id = threads.addThread(ds18b20_thread_fn, 0, 2048);
    // Restrict the thread to 1 tick (1ms) so it doesn't starve the main loop
    threads.setTimeSlice(ds18b20_thread_id, 1);
    DEBUG_PRINT("[+] DS18B20 background thread started, id=");
    DEBUG_PRINTLN(ds18b20_thread_id);

    // Start BME280 background thread - init_env_temp() has already configured
    bme280_thread_id = threads.addThread(bme280_thread_fn, 0, 2048);
    threads.setTimeSlice(bme280_thread_id, 1);
    DEBUG_PRINT("[+] BME280 background thread started, id=");
    DEBUG_PRINTLN(bme280_thread_id);
    DEBUG_PRINTLN("[+] setup() complete");
}

/**
 * Main control loop
 *
 * Executes continuously with multi-rate task scheduling based on
 * flags set by 1ms timer ISR. Task priorities:
 *
 * Continuous (every iteration):
 * - Update speed and torque measurements
 * - DS18B20 state machine
 * - CAN RX/TX processing
 * - Connection watchdog check
 *
 * 1ms tasks (1000Hz):
 * - PID control execution
 *
 * 10ms tasks (100Hz):
 * - Real-time data streaming (speed, torque, acceleration)
 * - Debug data transmission
 *
 * 100ms tasks (10Hz):
 * - CAN heartbeat
 * - Current and voltage measurement
 *
 * 500ms tasks (2Hz):
 * - System status broadcast
 *
 * 1s tasks (1Hz):
 * - Brake temperature measurement and transmission
 * - DS18B20 temperature transmission
 * - Ongoing config sync service
 *
 * 5s tasks (0.2Hz):
 * - Environmental sensor (BME280)
 */
void loop(void)
{
    uint8_t pending_1ms = 0;
    uint8_t pending_10ms = 0;
    uint8_t pending_100ms = 0;
    uint8_t pending_500ms = 0;
    uint8_t pending_1s = 0;
    uint8_t pending_5s = 0;

    // Continuous tasks (every iteration)
    update_speed();              // Read encoder, calculate RPM
    update_torque();             // Read load cell, calculate torque

    check_new_can_message();       // Check hardware for RX messages
    process_can_tx_queue();       // Send queued CAN messages
    parse_can_message();          // Process received CAN messages
    request_can_config();         // Non-blocking config sync service

    // Connection watchdog (reset by heartbeat, checked every loop)
    if (millis() - last_security_time_check > SECURITY_CHECK_INTERVAL)
    {
        status.connected = false; // Timeout - no heartbeat
    }
    enforce_disconnect_failsafe();

    // Atomically consume pending scheduler ticks and count skipped cycles.
    __disable_irq();
    pending_1ms = time_control.pending_1ms;
    pending_10ms = time_control.pending_10ms;
    pending_100ms = time_control.pending_100ms;
    pending_500ms = time_control.pending_500ms;
    pending_1s = time_control.pending_1s;
    pending_5s = time_control.pending_5s;
    time_control.pending_1ms = 0;
    time_control.pending_10ms = 0;
    time_control.pending_100ms = 0;
    time_control.pending_500ms = 0;
    time_control.pending_1s = 0;
    time_control.pending_5s = 0;
    if (pending_1ms > 1) time_control.missed_1ms += (pending_1ms - 1);
    if (pending_10ms > 1) time_control.missed_10ms += (pending_10ms - 1);
    if (pending_100ms > 1) time_control.missed_100ms += (pending_100ms - 1);
    if (pending_500ms > 1) time_control.missed_500ms += (pending_500ms - 1);
    if (pending_1s > 1) time_control.missed_1s += (pending_1s - 1);
    if (pending_5s > 1) time_control.missed_5s += (pending_5s - 1);
    __enable_irq();

    // === 1ms tasks (1000Hz nominal) === //
    if (pending_1ms > 0)
    {
        run_pid(); // Execute PID control
    }

    // === 10ms tasks (100Hz nominal) === //
    if (pending_10ms > 0)
    {
        status.current_timestamp = millis();

        if (status.live_mode == TRUE || status.status == RUNNING)
        {
            // Primary telemetry: filtered speed and torque
            send_speed_torque_timestamp(status);

            // Debug data (raw values for diagnostics)
            if (config.debug_mode == TRUE)
            {
                send_pid_debug_data(config, status);
                send_speed_torque_debug_timestamp(status);
                send_acceleration_debug_timestamp(status);
            }

            // Acceleration data
            send_acceleration_timestamp(status);
        }
    }

    // === 100ms tasks (10Hz) === //
    if (pending_100ms > 0)
    {
        send_heartbeat();           // Microcontroller heartbeat
        status.current = read_brake_current(); // Hall sensor current
        send_electrical_data(status); // Voltage + current
    }

    // === 500ms tasks (2Hz) === //
    if (pending_500ms > 0)
    {
        send_can_status(status); // System status broadcast
    }

    // === 1s tasks (1Hz) === //
    if (pending_1s > 0)
    {
        read_brake_temperature(status);    // MLX90614 IR sensor
        send_brake_temperature(status);    // Transmit brake temp
        send_ds18b20_temperature(status);  // DS18B20 ambient temp
    }

    // === 5s tasks (0.2Hz) === //
    if (pending_5s > 0)
    {
        send_env(status);  // Send temp and humidity
    }

    threads.yield();
}

// PID CONTROL DISPATCHERS

/**
 * Main PID dispatcher
 */
void run_pid(void)
{
    /* Dynamic Mode - Acceleration test state machine */
    if (config.mode.mode == DYNAMIC_MODE && status.status == RUNNING && status.valid_checksum)
    {
        run_dynamic_pid();
    }
    /* Acceleration Mode - Controls acceleration rate */
    else if (config.mode.mode == ACCELERATION_MODE && status.status == RUNNING && status.valid_checksum)
    {
        run_acceleration_pid();
    }
    /* Torque Mode - Constant torque control */
    else if (config.mode.mode == TORQUE_MODE && status.status == RUNNING && status.valid_checksum)
    {
        run_torque_pid();
    }
    /* Speed Mode - Constant RPM control */
    else if (config.mode.mode == SPEED_MODE && status.status == RUNNING && status.valid_checksum)
    {
        run_speed_pid();
    }
    /* Stopped and not manual mode - Safety: PWM off */
    else if (status.status == STOPPED && !status.manual_pwm_enabled)
    {
        set_pwm(0, config, outputFilter, status);
    }
}

// DYNAMIC TESTING STATE MACHINE

/**
 * Transition to new dynamic test state
 */
static void dyno_enter_state(dynamic_dyno_state s)
{
    dyno_state = s;

    // Update status info message for each state
    switch (s)
    {
    case IDLE:
        status.info = INFO_MSG_IDLE;
        break;
    case SPINUP_TO_START_SPEED:
        status.info = INFO_MSG_SPINUP;
        break;
    case WAIT_STABLE:
        status.info = INFO_MSG_WAIT_STABLE;
        break;
    case ACCELERATING:
        status.info = INFO_MSG_ACCELERATING;
        break;
    case HOLD_TOP_SPEED:
        status.info = INFO_MSG_HOLD_TOP_SPEED;
        break;
    case WAIT_TORQUE_DROP:
        status.info = INFO_MSG_WAIT_TORQUE_DROP;
        break;
    case DECELERATING:
        status.info = INFO_MSG_DECELERATING;
        break;
    case FINISHED:
        status.info = INFO_MSG_FINISHED;
        break;
    default:
        break;
    }
    send_can_status(status); // Notify server of state change
}
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

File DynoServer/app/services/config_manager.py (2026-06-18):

import json
import struct
from time import time
from pathlib import Path
from dataclasses import dataclass
from typing import List, Dict, Any
from app.services.can_commands import CANCommands
from app.services.input_validation import (
    ValidationError,
    validate_full_config_payload,
    validate_fast_config_payload,
)

# Manages system configuration persistence and CRC16 checksum calculation
class ConfigManager:

    def __init__(self, path: str, system_manager):

        self.system_manager = system_manager
        self.file_path = Path(path)
        self._validate_config_file()

        self.config_data = self._load_config()
        self.status = "Stopped"
        self.live_mode = 1
        self.pwm_value = 0
        self.debug = self.config_data.get("debug", {}).get("enabled", False)
        self.info = "Stopped"
        self.connected = False
        self.run_mode_value =self.config_data.get("runMode", {}).get("value", 0)
        self.run_mode = self.config_data.get("runMode", {}).get("mode", 10)

        # Track last time struct size was logged (for throttling)
        self._last_struct_log_time = 0
        self.last_error = ""
        self.last_error_is_validation = False

    # Validate config file
    def _validate_config_file(self) -> None:
        if not self.file_path.exists():
            raise FileNotFoundError(f"Config file not found: {self.file_path}")
        if not self.file_path.is_file():
            raise ValueError(f"Path is not a file: {self.file_path}")

    # Load config from file
    def _load_config(self) -> Dict[str, Any]:
        with open(self.file_path, 'r') as f:
            return json.load(f)

    # Convert config to dict
    def to_dict(self) -> Dict[str, Any]:
        return {
            "status": self.status,
            "debug": self.debug,
            "info": self.info,
            "live_mode" : self.live_mode,
            "connected": self.connected,
            "pwm_value" : self.pwm_value,
            "mode" : self.run_mode,
            "value" : self.run_mode_value
        }

    # Get fast config
    def get_fast_config(self) -> Dict[str, Any]:
        config_data = self._load_config()
        keys = ['launch', 'ratio', 'runMode', 'live_graph', 'debug_graph', 'torque_graph', 'speed_graph', 'dynamic_graph', 'display_filter']
        return {key: config_data[key] for key in keys if key in config_data}

    # Get config
    def get_config(self) -> Dict[str, Any]:
        return self._load_config()
    
    # Get checksum
    def get_checksum(self):
        return self.config_data['checksum']

    # Set error
    def _set_error(self, message: str, is_validation: bool) -> None:
        self.last_error = message
        self.last_error_is_validation = is_validation

    # Set config
    def set_config(self, data: Dict[str, Any]) -> bool:
        try:
            current_config = self._load_config()
            normalized_config = validate_full_config_payload(data, current_config)
            self.debug = normalized_config.get("debug", {}).get("enabled", False)
            self._save_config(normalized_config)
            self._set_error("", False)
            return True
        except ValidationError as e:
            self._set_error(str(e), True)
            print(f"Config validation error: {e}")
            return False
        except Exception as e:
            self._set_error("Failed to save configuration.", False)
            print(f"Error setting config: {e}")
            return False
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

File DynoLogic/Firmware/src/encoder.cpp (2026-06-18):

// =============================================================================
// encoder.cpp - Hardware-based period speed measurement
//
// This file implements the encoder driver entirely in i.MX RT1062 hardware
// peripherals.
//
//   - ENC1 (Quadrature Decoder peripheral) handles edge counting
//     autonomously on pins 2/3. With 4x quadrature decoding and a 50 PPR
//     encoder this gives 200 counts/rev.
//
//   - TMR2 channels 0 and 1 cascaded into a 32-bit free-running counter
//     clocked at IPG_BUS/8 (~18.75 MHz). On every rising edge of phase A
//     the counter value is captured into the CAPT registers without
//     CPU involvement.
//
//   - XBARA1 fans pin 2's signal out to BOTH ENC1_PHASEA and
//     QTIMER2_TIMER0 simultaneously.
//
//   - The main loop reads TMR2's last captured period via
//     encoder_pop_rad_s(). Speed always comes from time between phase-A
//     pulses; ENC1 is used only for hardware quadrature direction.
// =============================================================================

#include "pins.h"
#include "config.h"
#include "encoder.h"

#include <math.h>
#include <Arduino.h>
#include <QuadEncoder.h>

// =============================================================================
// HARDWARE OBJECTS / STATE
// =============================================================================

// QuadEncoder takes (channel, phaseA pin, phaseB pin). Channel 1 maps to
// the ENC1 peripheral. The constructor performs the pad-mux and XBAR1
// routing for both pins automatically (also enables the XBAR1 clock).
static QuadEncoder enc1(1, ENC_A_PIN, ENC_B_PIN, 0);

// TMR2 capture state. All three are written by the qtimer2 ISR and read
// from the main / PID context, so they are volatile and the read side
// must mask interrupts while sampling.
static volatile uint32_t s_last_capture_ticks = 0;  // Most recent absolute timer value (32-bit cascaded)
static volatile uint32_t s_period_ticks       = 0;  // Most recent capture-to-capture delta
static volatile bool     s_period_fresh       = false;
static volatile bool     s_new_measure        = false;


// Cached XBAR output index for QTIMER2_TIMER0's capture input. Verified
// in imxrt.h: XBARA1_OUT_QTIMER2_TIMER0 == 90.
#ifndef XBARA1_OUT_QTIMER2_TIMER0
#define XBARA1_OUT_QTIMER2_TIMER0 90
#endif

// Pin 2 maps to XBAR1_INOUT06 in the Teensy 4.x pin table (see
// QuadEncoder hardware table). The constant matches the index used by
// the QuadEncoder library when it routed the same input to ENC1.
static const unsigned int XBAR_INPUT_PIN2 = 6;

// =============================================================================
// RATIO-BASED OUTLIER REJECTOR (period domain)
// Rejects a new period sample if it is >1.9x or <0.526x the last
// accepted period (mirrors the commercial product's 1.9x/0.526x test).
// After MAX_CONSEC_REJECTS rejections in a row we re-converge on the
// new value and latch a glitch flag for the host to surface.
// =============================================================================
#define RATIO_HIGH         1.9f
#define RATIO_LOW          0.526f
#define MAX_CONSEC_REJECTS 10

static uint32_t last_accepted_period = 0;
static uint8_t  consec_rejects       = 0;
static volatile bool speed_glitch_latched = false;

/**
 * Apply the ratio-based acceptance test to a new period sample.
 *
 * Returns true if the sample was accepted (and updates the running last-
 * accepted reference). Returns false if the sample was rejected; after
 * MAX_CONSEC_REJECTS successive rejects the function force-accepts to
 * re-converge and sets speed_glitch_latched.
 */
static inline bool ratio_accept_period(uint32_t new_period) {
  if (last_accepted_period == 0) {
    last_accepted_period = new_period;
    consec_rejects = 0;
    return true;
  }
  const float r = (float)new_period / (float)last_accepted_period;
  if (r > RATIO_HIGH || r < RATIO_LOW) {
    if (consec_rejects < 255) consec_rejects++;
    if (consec_rejects >= MAX_CONSEC_REJECTS) {
      speed_glitch_latched = true;
      last_accepted_period = new_period;
      consec_rejects = 0;
      return true;
    }
    return false;
  }
  last_accepted_period = new_period;
  consec_rejects = 0;
  return true;
}

bool encoder_consume_glitch_flag() {
  noInterrupts();
  bool v = speed_glitch_latched;
  speed_glitch_latched = false;
  interrupts();
  return v;
}

// =============================================================================
// LOCAL STATE FOR PERIOD-BASED SPEED MEASUREMENT
// =============================================================================
static double   s_last_report_rpm = 0.0;
static uint32_t s_last_capture_seen_us = 0; // Wall-clock of last fresh T-method update (timeout detection)
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

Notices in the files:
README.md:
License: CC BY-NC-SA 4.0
